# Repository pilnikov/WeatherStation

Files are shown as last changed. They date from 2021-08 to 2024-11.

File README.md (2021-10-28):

# WeatherStations

Проект метеостанции на ESP8266/32 (среда - Arduino IDE 1.8.5)

Поддерживаются:

Дисплеи на 7ми и 14ти сегментных индикаторах с драйверами на TM1637, HT16K33, MAX7219 (4/8 Знакомест).

LCD16х2 дисплей со встроеным знакогенератором кириллицы, интерфейс  I2C.

Матричные дисплеи на:
        
        MAX7219 8х32 и 16х32 пикселей.
        отдельном контроллере MEGA2560, 16х32 пикселей, полный цвет, интерфейс HUB75
        в версии ЕСП32, 64х64 пикселей, полный цвет, интерфейс HUB75 
        Holtek HT1632, 16х32 пикселей, 3 цвета (R, G, Orange) от Sure Electronics

Модули RTC на DS1307, DS1302, DS3231.

Управление яркостью дисплеев посредством датчика освещенности ВН1750 или фоторезистора.

Погодные датчики DHT22, Si7021, BME(/P)085/180/280, AM2320, вcтроеный в DS3231 датчик температуры.

Обмен данными между 2мя и более устройствами внутри сети посредством JSON запросов и через облачный сервис ThingSpeak.

Клиент/серверная архитектура.

Возможность работы в режиме "WiFi датчик".

Прогноз погоды с GisMeteo и OpenWeatherMap.

Синхронизация времени с NTP.

6 многофункциональных будильников с 15ю мелодиями.

Настойка через веб интерфейс.

Обновление по OTA, mdns.

Новости с newsapi.

Конфигурирование GPIO.

Дауншифтовая версия на MEGA2560 без возможности перенастройки, без прогноза, без новостей.

Немного мультиков
https://yadi.sk/i/UXBMaSDD3HfCZC

https://yadi.sk/i/Ew0egvWq3Hg48u

https://yadi.sk/i/os1wRLuz3Hg493

https://yadi.sk/i/jCs5TbVB3aA5pw теперь только один мк, безо всяких мег

https://youtu.be/F3vVPQLzyJk версия с новостями, там же есть ссылки на фото платы

Cхемы в папочке extras, там же и инфа для изготовления печатных плат.

Файлы из папки Data необходимо залить на LittleFS плагином (лежат в  папке dop).

По умолчанию первый раз запускается точка доступа с именем  Web_Clock и паролем 12345678 (задается в файле config.json из папки data перед загрузкой в LittleFS строкой  "ap_ssid":"Web_Clock","ap_pass":"12345678").Веб интерфейс будет доступен по адресу 192.168.4.1.

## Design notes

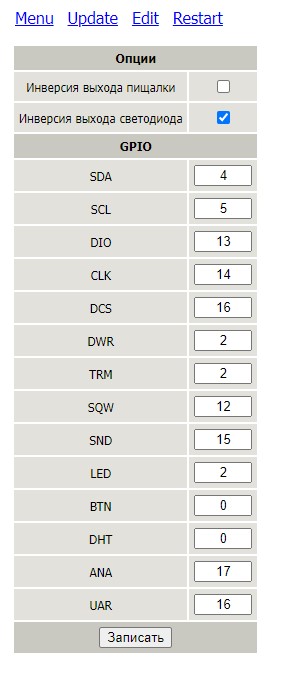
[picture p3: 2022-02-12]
wc_rt1/images/gpio.JPG

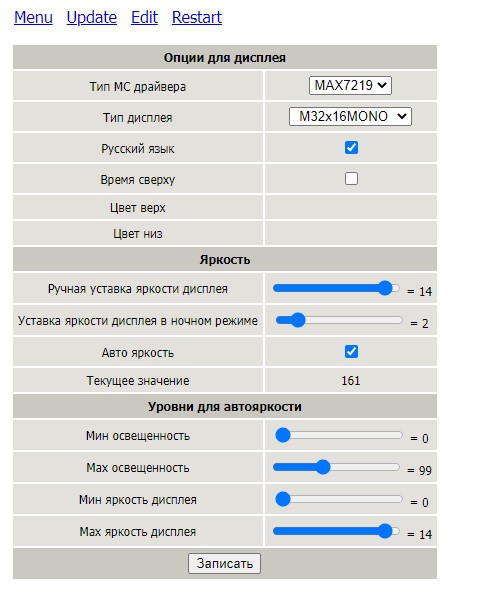
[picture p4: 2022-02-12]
wc_rt1/images/disp.JPG

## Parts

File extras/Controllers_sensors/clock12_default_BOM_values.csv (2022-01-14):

Qty | Value | Device | Parts | Description | OC_FARNELL | OC_NEWARK | PROD_ID | VALUE
10 | 10u | CAP0603-CAP | C101, C102, C104, C105, C108, C111, C112, C205, C206, C210 | Capacitor
13 | 0.1u | CAP0603-CAP | C103, C106, C107, C109, C201, C203, C207, C208, C211, C212, C302, C303, C307 | Capacitor
9 | 1u | CAP0603-CAP | C110, C113, C114, C115, C202, C204, C209, C305, C306 | Capacitor
2 | 22u | CAP0603-CAP | C301, C304 | Capacitor
1 | 1N5819 | DIODE-SOD123 | D201 | DIODE
1 | CRG | LED-YELLOW0603 | D202 | Yellow SMD LED |  |  | DIO-09003 | Yellow
2 | IN5819 | DIODE-SOD123 | D301, D302 | DIODE
1 | BATTERY-LI-MH12210 | BATTERY-LI-MH12210 | G201 | Lithium-Ion MH12210 Rechargeable Battery
1 | ESP32C3 | ESP32C3-MODULE32S | IC101
1 | ESP32 | ESP32-MODULEDUAL | IC102
1 | ESP32C3-MODULE13U | ESP32C3-MODULE13U | IC103
1 | ESP32S2 | ESP32S2-MODULEAI | IC104
5 | AP2112 | V_REG_LDOSMD | IC201, IC301, U101, U102, U103 | Voltage Regulator LDO |  |  | VREG-12457
1 | SI7021 | SI7021 | IC202 | Silicon Labs Si7021 I2C Humidity and Temperature Sensor |  |  | IC-13093
1 | MCP73831 | MCP73831 | IC203 | Miniature single cell, fully integrated Li-Ion, Li-polymer charge management controller |  |  | IC-09995
1 | BME280 | BME280 | IC204 | Bosch BME280 &ndash; Combined Humidity and Pressure Sensor |  |  | IC-13090 | BME280
1 | BH1750 | BH1750 | IC205 |  |  |  | IC-13876 | ZOPT2201
1 | CP2102 | CP2102-GMR(QFN28) | IC302 | 310070003 |  |  |  | CP2102-GMR-QFN28
3 |  | USB_MICRO-BFEMALE_SMT_ | J101, J106, J107 | USB Type Micro-B Connector
4 | COM | HEADER-2X3SMT | J102, J103, J104, J105 | PIN HEADER
2 |  | HEADER-2X8 | J108, J111 | PIN HEADER
2 |  | HEADER-2X13 | J109, J110 | PIN HEADER
2 |  | USB_C16PIN | J201, J302 | USB Type C 16Pin Connector |  |  | CONN-14122
1 | FR | CONN_03 | J202 | Multi connection point. Often used as Generic Header-pin footprint for 0.1 inch spaced/style header connections |  |  | XXX-00000 | 455-1750-1-ND
1 |  | HEADER-2X5 | J203 | PIN HEADER
1 | DHT22 | C-GRID-04-70543 | J204 | CONNECTOR | unknown | unknown
2 | +5V | C-GRID-02-70543 | J205, J303 | CONNECTOR | unknown | unknown
1 | AM2320 | C-GRID-04-70543 | J206 | CONNECTOR | unknown | unknown
1 | LiPo | CONN_02-JST-2MM-SMT | J207 | Multi connection point. Often used as Generic Header-pin footprint for 0.1 inch spaced/style header connections |  |  | CONN-11443
1 | PROG | JST-SH-1MM-8 | J301
1 | COM1 | HEADER-2X3SMT_1.27 | J304 | PIN HEADER
1 | COM2 | HEADER-2X3SMT | J305 | PIN HEADER
1 | 2301 | MOSFET-PCHANNELDMG2307L | Q201 | Generic PMOSFET |  |  | TRANS-11308 | 2.5A/30V
1 |  | SMD-MOSFET-DUAL-N-CH-30V-2.9A-SI5902DC-T1-E3(1206-8)SOT363 | Q301 | 305040005
6 | 100k | R-EU_R0603 | R101, R103, R104, R206, R207, R301 | RESISTOR, European symbol
10 | 10k | R-EU_R0603 | R102, R105, R106, R107, R204, R210, R212, R303, R304, R305 | RESISTOR, European symbol
2 | 47k | R-EU_R0603 | R201, R202 | RESISTOR, European symbol
2 | 5.1k | R-EU_R0603 | R203, R302 | RESISTOR, European symbol
1 | 27k | R-EU_R0603 | R205 | RESISTOR, European symbol
3 | 1k | R-EU_R0603 | R208, R209, R215 | RESISTOR, European symbol
3 | 2k | R-EU_R0603 | R211, R307, R308 | RESISTOR, European symbol
2 | 3k3 | R-EU_R0603 | R213, R214 | RESISTOR, European symbol
1 | 4.7k | R-EU_R0603 | R306 | RESISTOR, European symbol
5 | RST | MICROSWITCH-BUTTON | SW101, SW103, SW104, SW105, SW301
5 | PRG | MICROSWITCH-BUTTON | SW102, SW106, SW107, SW108, SW302
1 | MICROSWITCH-BUTTONANGLE | MICROSWITCH-BUTTONANGLE | SW201
1 | BAT ON | SMD-TOGGLE-SWITCH-ON-ON(3+4P-6.7X2.7MM)ORIG | SW202 | 311030001

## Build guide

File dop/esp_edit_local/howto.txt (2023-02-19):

Для работы требуется написать в браузере "путь/index.htm?url=server". 
Вместо server к примеру пишем 192.168.211.180. 
Например у меня это выглядит так "C:/esp_edit_local/index.htm?url=192.168.211.180". 

Но есть одна ложка дегтя, не все браузеры поддерживают обработку параметров. 
11 Internet Explorer выдает ошибку, но в Edge все работает. 
У кого будет ошибка "файл не найден", вам надо править в файле index.htm переменную urlXXX. 
Очень важно косую не ставить в конце.

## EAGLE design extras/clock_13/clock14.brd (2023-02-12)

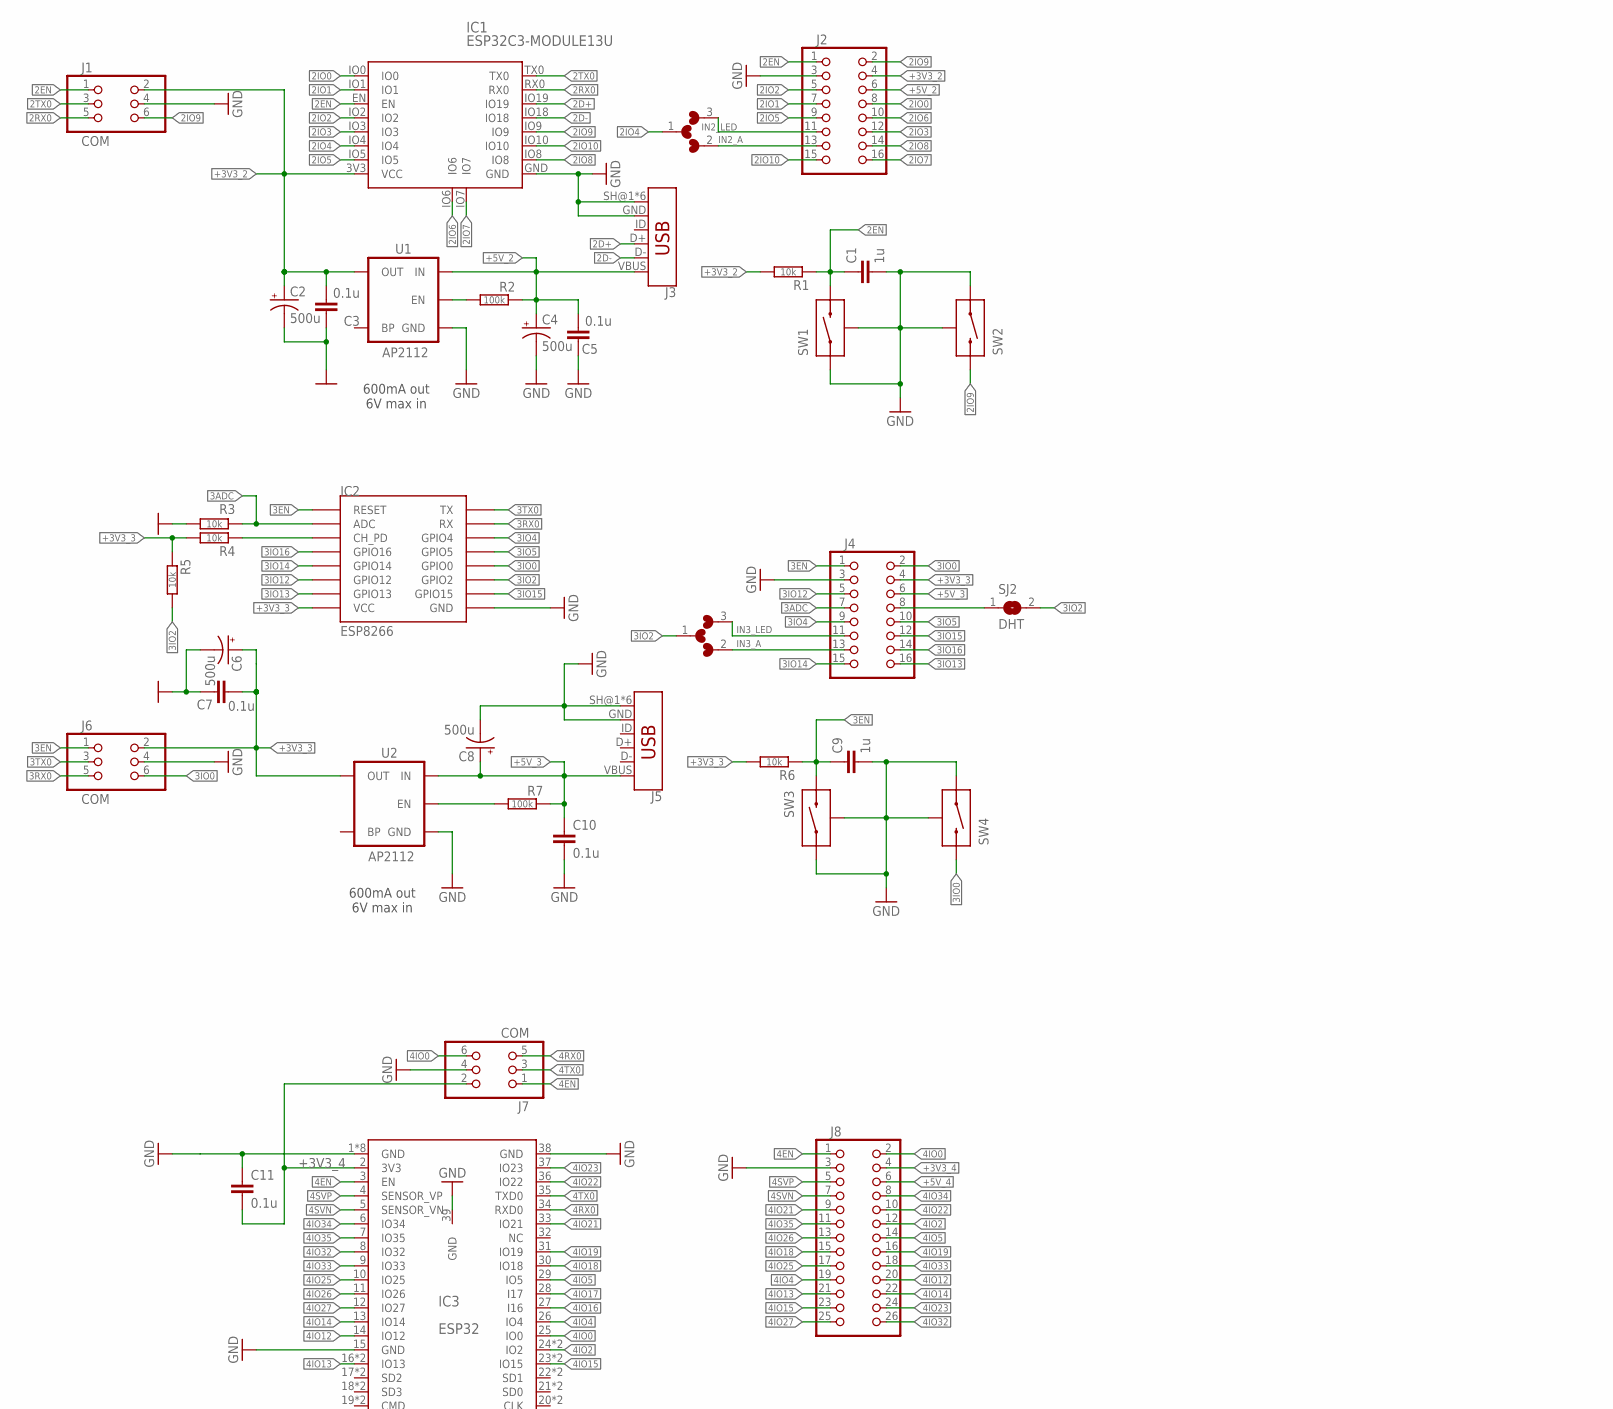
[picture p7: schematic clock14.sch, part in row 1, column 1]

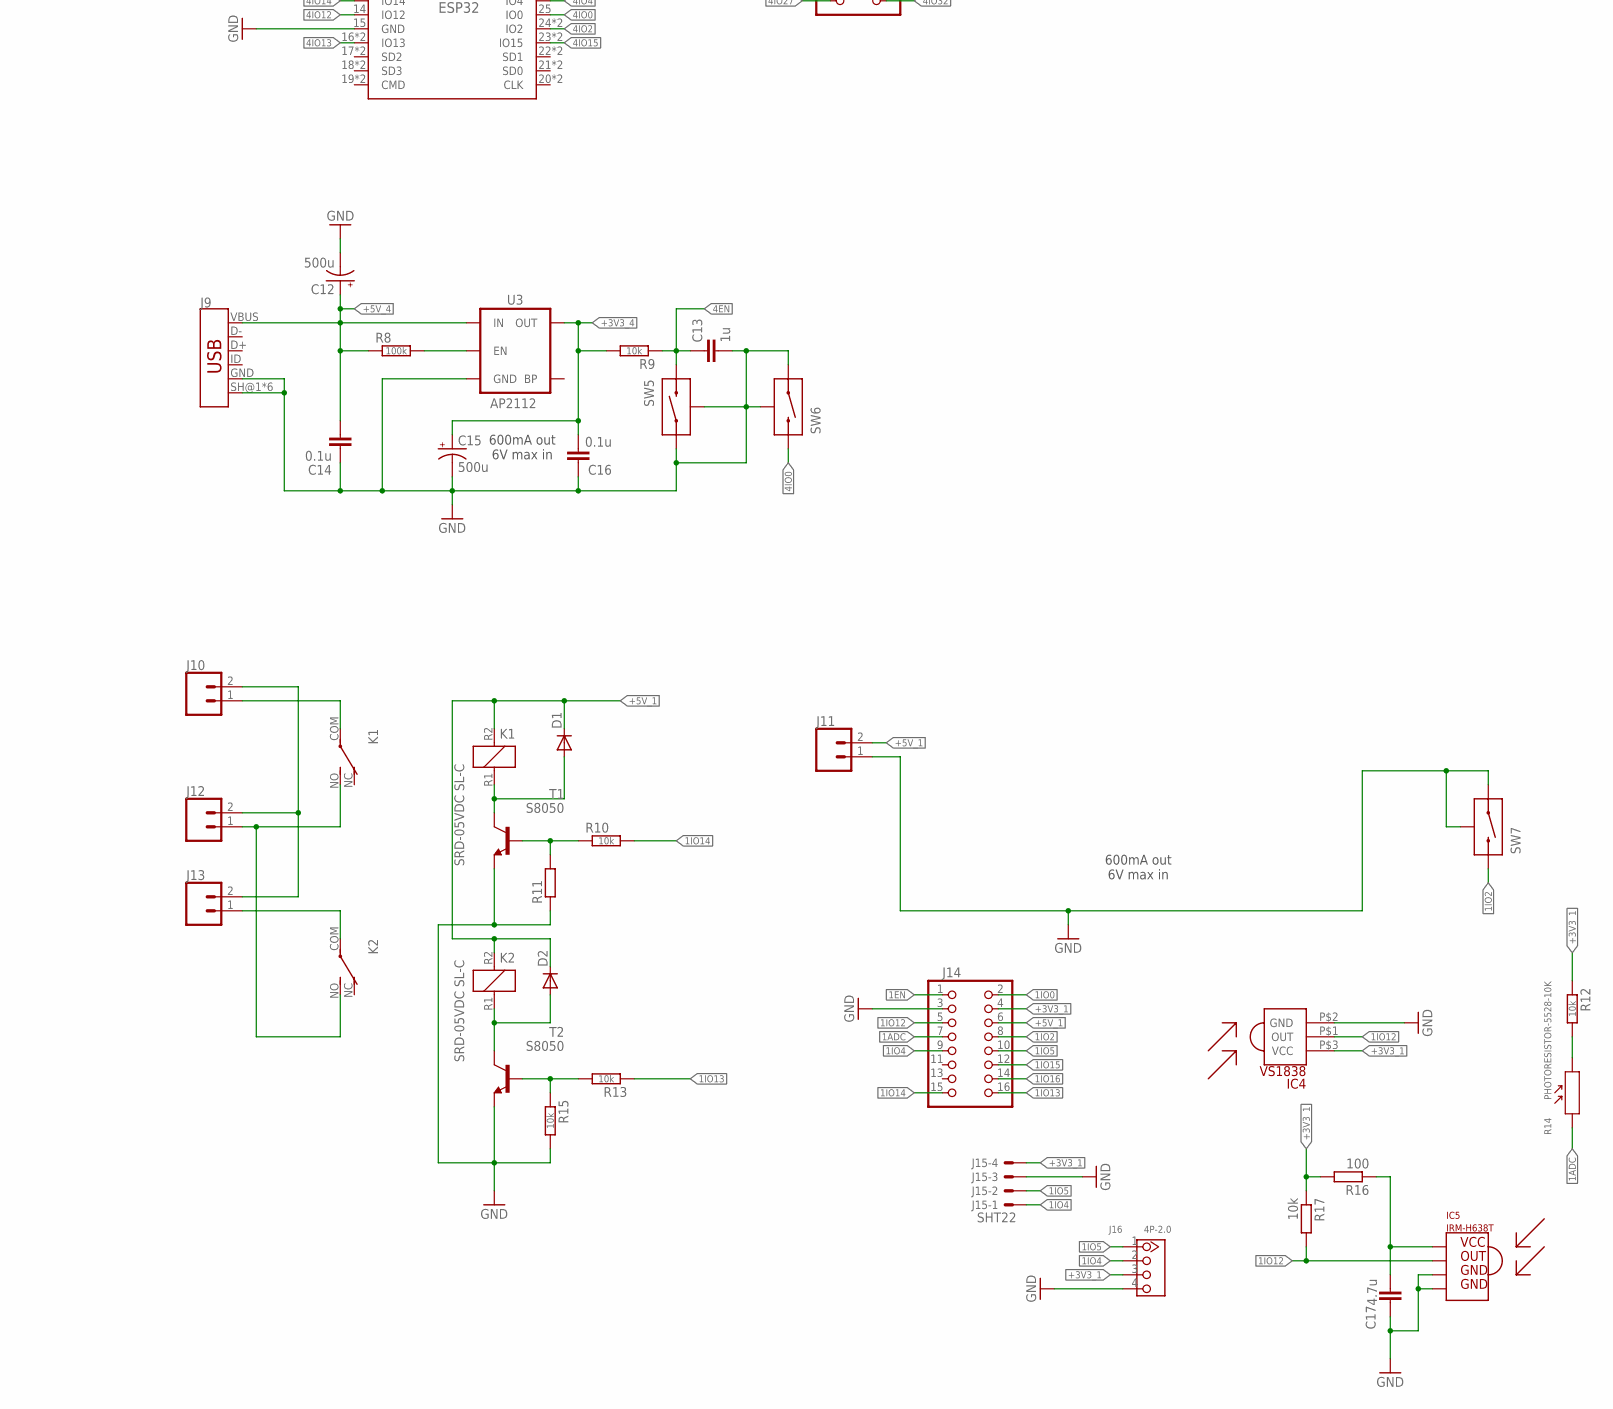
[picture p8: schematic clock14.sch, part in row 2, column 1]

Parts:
C1, C9, C13: 1u; 0603-CAP
C2, C4, C6, C8, C12, C15: 500u; CPOL-RADIAL-100UF-25V
C3, C5, C7, C10, C11, C14, C16: 0.1u; 0603-CAP
C17: 4.7u; 0603-CAP
D1, D2: DIODE-SOD123; SOD123
IC1: ESP32C3-MODULE13U; ESP32C3-13U
IC2: ESP8266; ESP12-SMD
IC3: ESP32; ESP32-WROOVER/WROOM
IC4: VS1838; IR
IC5: IRM-H638T
J1, J6, J7: COM; 2X03_SMT
J2, J4, J14: HEADER-2X8; 2X8
J3, J5, J9: USB_MICRO-BFEMALE_SMT_; USB-B-MICRO-SMD_MY
J8: HEADER-2X13; 2X13
J10, J11, J12, J13: CONN_02; 1X02
J15: SHT22; 70543-04
J16: 4P-2.0; HW4-2.0
K1, K2: SRD-05VDC SL-C; SL-C
R1, R3, R4, R5, R6, R9, R10, R12, R13, R15, R17: 10k; R0603
R2, R7, R8: 100k; R0603
R11: R-EU_R0603; R0603
R14: PHOTORESISTOR-5528-10K; SNR2-3.0
R16: 100; R0603
SJ1, SJ3: L/W; MICROBUILDER_SOLDERJUMPER_ARROW_NOPASTE_3
SJ2: DHT; MICROBUILDER_SOLDERJUMPER_ARROW_NOPASTE
SW1, SW3, SW5: RST; MICROPUSH-BUT_TOP
SW2, SW4, SW6, SW7: PRG; MICROPUSH-BUT_TOP
T1, T2: S8050; SOT23-EBC
U1, U2, U3: AP2112; SOT23-5

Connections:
1ADC: J14.7, R14.1
1EN: J14.1
1EN_P: R8.2, U3.3 (EN)
1IO0: J14.2
1IO2: J14.8, SW7.B
1IO4: J14.9, J15.1, J16.2
1IO5: J14.10, J15.2, J16.1
1IO12: IC4.P$1 (OUT), IC5.OUT, J14.5, R17.2
1IO13: J14.16, R13.1
1IO14: J14.15, R10.2
1IO15: J14.12
1IO16: J14.14
2D+: IC1.IO19, J3.D+
2D-: IC1.IO18, J3.D-
2EN: C1.1, IC1.EN, J1.1, J2.1, R1.1, SW1.B
2EN_P: R2.2, U1.3 (EN)
2IO0: IC1.IO0, J2.8
2IO1: IC1.IO1, J2.7
2IO2: IC1.IO2, J2.5
2IO3: IC1.IO3, J2.12
2IO4: IC1.IO4, SJ1.1
2IO5: IC1.IO5, J2.9
2IO6: IC1.IO6, J2.10
2IO7: IC1.IO7, J2.16
2IO8: IC1.IO8, J2.14
2IO9: IC1.IO9, J1.6, J2.2, SW2.B
2IO10: IC1.IO10, J2.15
2RX0: IC1.RX0, J1.5
2TX0: IC1.TX0, J1.3
3ADC: IC2.ADC, J4.7, R3.1
3EN: C9.1, IC2.RESET, J4.1, J6.1, R6.1, SW3.B
3EN_P: R7.2, U2.3 (EN)
3IO0: IC2.GPIO0, J4.2, J6.6, SW4.B
3IO2: IC2.GPIO2, R5.2, SJ2.2, SJ3.1
3IO4: IC2.GPIO4, J4.9
3IO5: IC2.GPIO5, J4.10
3IO12: IC2.GPIO12, J4.5
3IO13: IC2.GPIO13, J4.16
3IO14: IC2.GPIO14, J4.15
3IO15: IC2.GPIO15, J4.12
3IO16: IC2.GPIO16, J4.14
3RX0: IC2.RXD0 (RX), J6.5
3TX0: IC2.TXD0 (TX), J6.3
4EN: C13.1, IC3.3 (EN), J7.1, J8.1, R9.1, SW5.B
4IO0: IC3.25 (IO0), J7.6, J8.2, SW6.B
4IO2: IC3.24 (IO2), IC3.48 (IO2), J8.12
4IO4: IC3.26 (IO4), J8.19
4IO5: IC3.29 (IO5), J8.14
4IO12: IC3.14 (IO12), J8.20
4IO13: IC3.16 (IO13), IC3.40 (IO13), J8.21
4IO14: IC3.13 (IO14), J8.22
4IO15: IC3.23 (IO15), IC3.47 (IO15), J8.23
4IO16: IC3.27 (I16)
4IO17: IC3.28 (I17)
4IO18: IC3.30 (IO18), J8.15
4IO19: IC3.31 (IO19), J8.16
4IO21: IC3.33 (IO21), J8.9
4IO22: IC3.36 (IO22), J8.10
4IO23: IC3.37 (IO23), J8.24
4IO25: IC3.10 (IO25), J8.17
4IO26: IC3.11 (IO26), J8.13
4IO27: IC3.12 (IO27), J8.25
4IO32: IC3.8 (IO32), J8.26
4IO33: IC3.9 (IO33), J8.18
4IO34: IC3.6 (IO34), J8.8
4IO35: IC3.7 (IO35), J8.11
4RX0: IC3.34 (RXD0), J7.5
4SVN: IC3.5 (SENSOR_VN), J8.7
4SVP: IC3.4 (SENSOR_VP), J8.5
4TX0: IC3.35 (TXD0), J7.3
+3V3_1: IC4.P$3 (VCC), J14.4, J15.4, J16.3, R12.1, R16.2, R17.1
+3V3_2: C2.1 (+), C3.2, IC1.3V3 (VCC), J1.2, J2.4, R1.2, U1.5 (OUT)
+3V3_3: C6.1 (+), C7.2, IC2.VCC, J4.4, J6.2, R4.2, R5.1, R6.2, U2.5 (OUT)
+3V3_4: C11.2, C15.1 (+), C16.2, IC3.2 (3V3), J7.2, J8.4, R9.2, U3.5 (OUT)
+5V_1: D1.C, D2.C, J11.2, J14.6, K1.R2 (2), K2.R2 (2)
+5V_2: C4.1 (+), C5.2, J2.6, J3.VBUS, R2.1, U1.1 (IN)
+5V_3: C8.1 (+), C10.1, J4.6, J5.VBUS, R7.1, U2.1 (IN)
+5V_4: C12.1 (+), C14.1, J8.6, J9.VBUS, R8.1, U3.1 (IN)
GND: C1.2, C2.2 (-), C3.1, C4.2 (-), C5.1, C6.2 (-), C7.1, C8.2 (-), C9.2, C10.2, C11.1, C12.2 (-), C13.2, C14.2, C15.2 (-), C16.1, C17.2, IC1.GND, IC2.GND, IC3.1 (GND), IC3.15 (GND), IC3.38 (GND), IC3.39 (GND), IC3.GND, IC3.PAD$1 (GND), IC3.PAD$4 (GND), IC3.PAD$5 (GND), IC3.PAD$7 (GND), IC3.PAD$8 (GND), IC3.PAD$9 (GND), IC4.P$2 (GND), IC5.GND, IC5.GND1, J1.4, J2.3, J3.GND, J3.SH@1 (SHIELD), J3.SH@2 (SHIELD), J3.SH@3 (SHIELD), J3.SH@4 (SHIELD), J3.SH@5 (SHIELD), J3.SH@6 (SHIELD), J4.3, J5.GND, J5.SH@1 (SHIELD), J5.SH@2 (SHIELD), J5.SH@3 (SHIELD), J5.SH@4 (SHIELD), J5.SH@5 (SHIELD), J5.SH@6 (SHIELD), J6.4, J7.4, J8.3, J9.GND, J9.SH@1 (SHIELD), J9.SH@2 (SHIELD), J9.SH@3 (SHIELD), J9.SH@4 (SHIELD), J9.SH@5 (SHIELD), J9.SH@6 (SHIELD), J11.1, J14.3, J15.3, J16.4, R3.2, R11.1, R15.2, SW1.A, SW1.SH0 (SH), SW2.A, SW2.SH0 (SH), SW3.A, SW3.SH0 (SH), SW4.A, SW4.SH0 (SH), SW5.A, SW5.SH0 (SH), SW6.A, SW6.SH0 (SH), SW7.A, SW7.SH0 (SH), T1.E, T2.E, U1.2 (GND), U2.2 (GND), U3.2 (GND)
IN2_A: J2.13, SJ1.2
IN2_LED: J2.11, SJ1.3
IN3_A: J4.13, SJ3.2
IN3_DHT: J4.8, SJ2.1
IN3_LED: J4.11, SJ3.3
IN_L: J12.1, K1.NO, K2.NO
N: J10.2, J12.2, J13.2
unnamed: IC2.CH_PD, R4.1
unnamed: D1.A, K1.R1 (1), T1.C
unnamed: R10.1, R11.2, T1.B
unnamed: D2.A, K2.R1 (1), T2.C
unnamed: R13.2, R15.1, T2.B
unnamed: R12.2, R14.2
unnamed: C17.1, IC5.VCC, R16.1
OUT_L1: J10.1, K1.COM
OUT_L2: J13.1, K2.COM

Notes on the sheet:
600mA out 6V max in

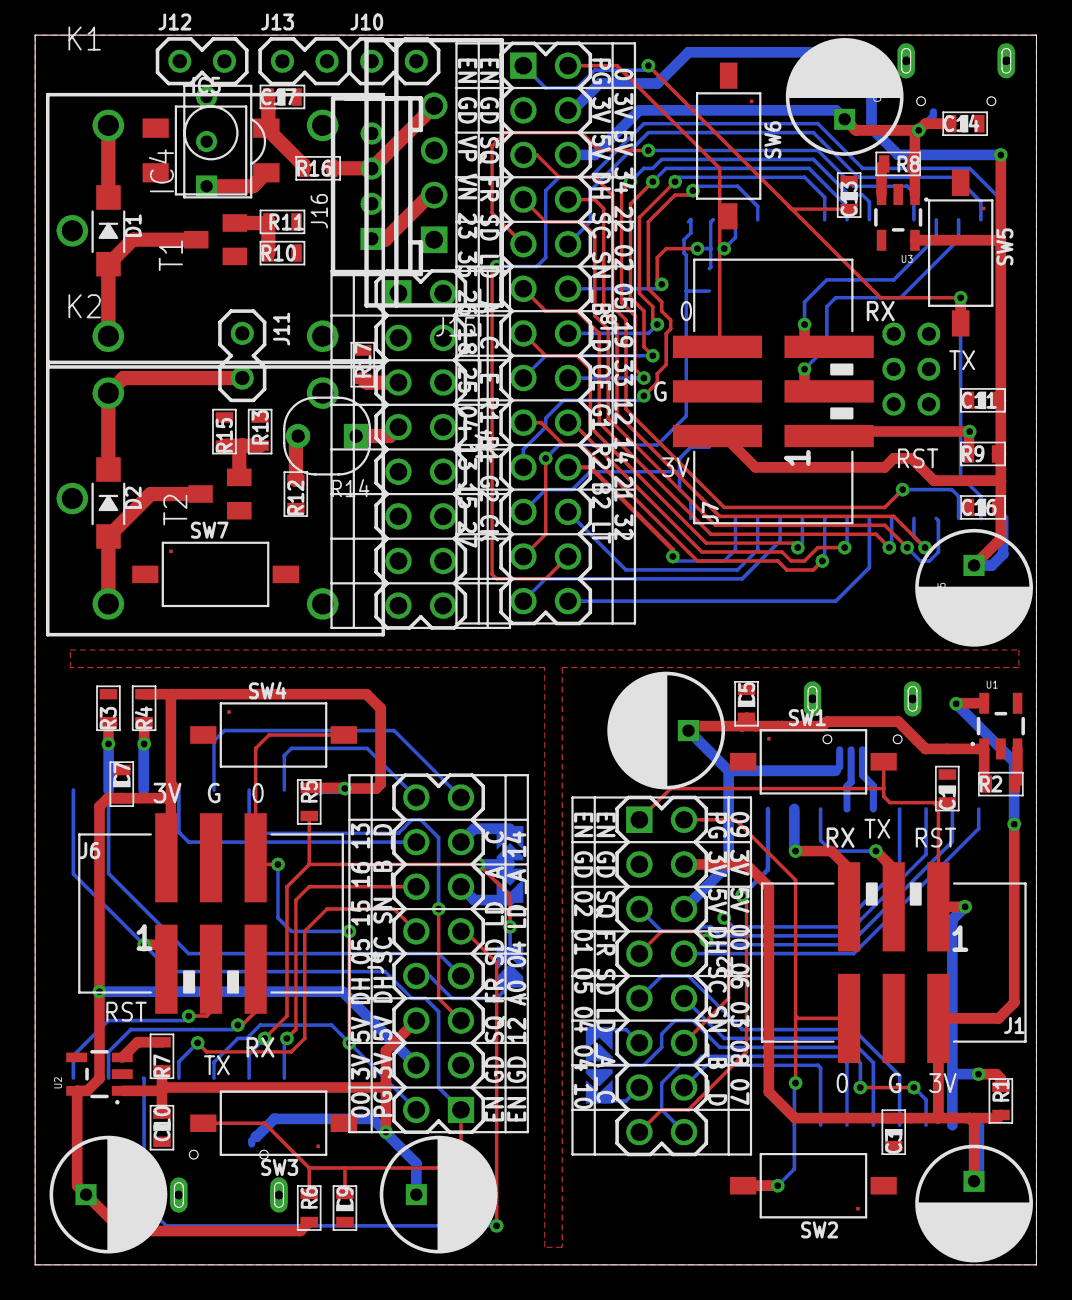
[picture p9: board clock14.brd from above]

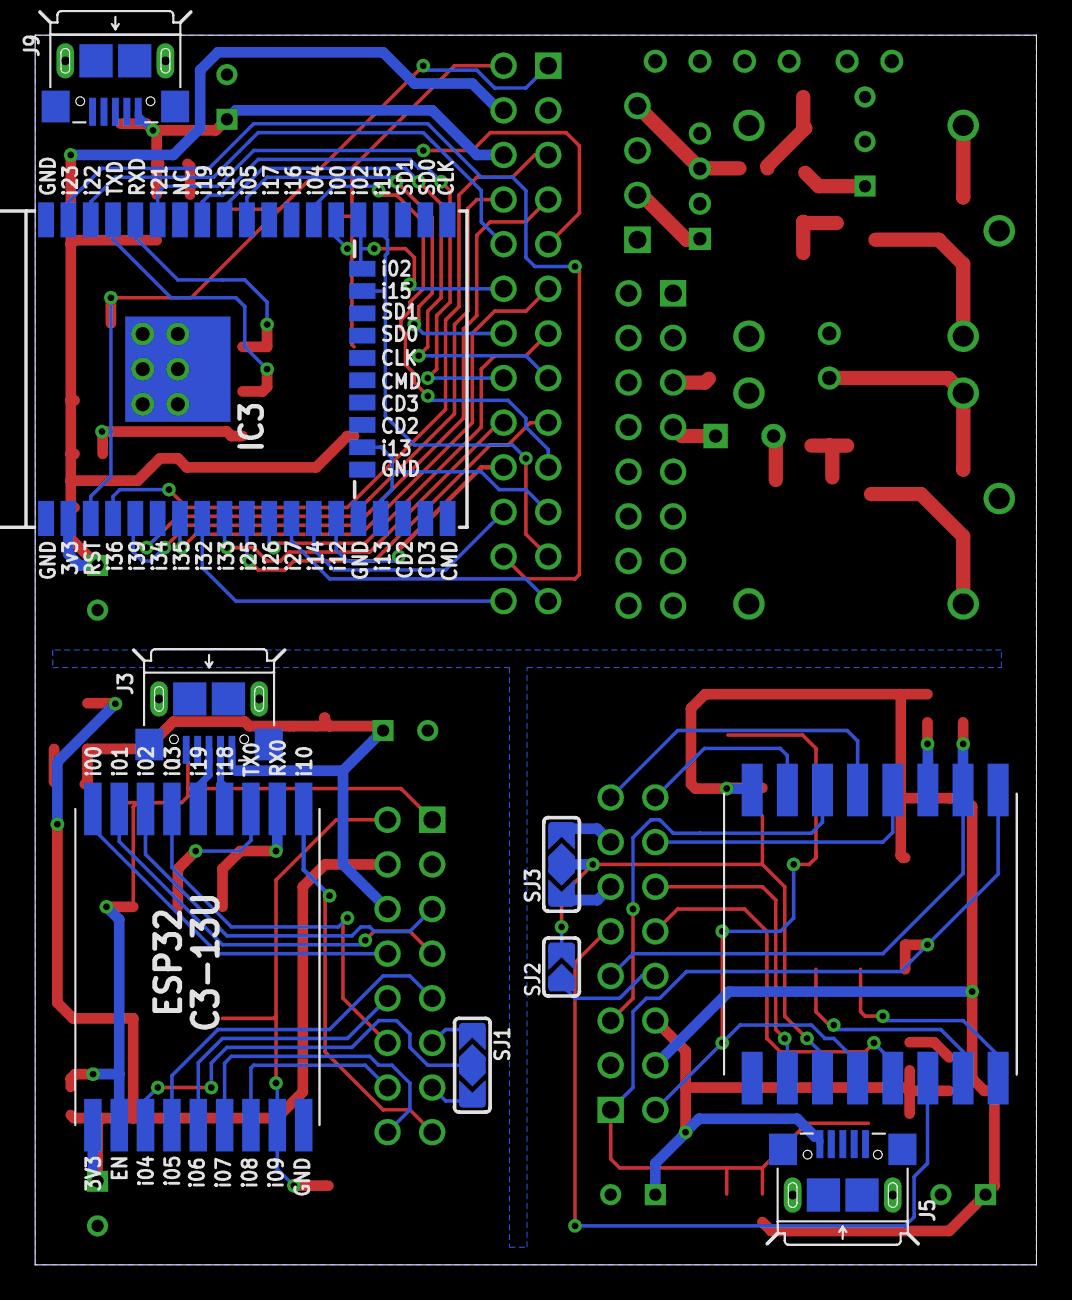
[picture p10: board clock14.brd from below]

Board: 2 copper layers, 57.0 x 70.0 mm, 74 parts (9 on the bottom side), 89 nets.

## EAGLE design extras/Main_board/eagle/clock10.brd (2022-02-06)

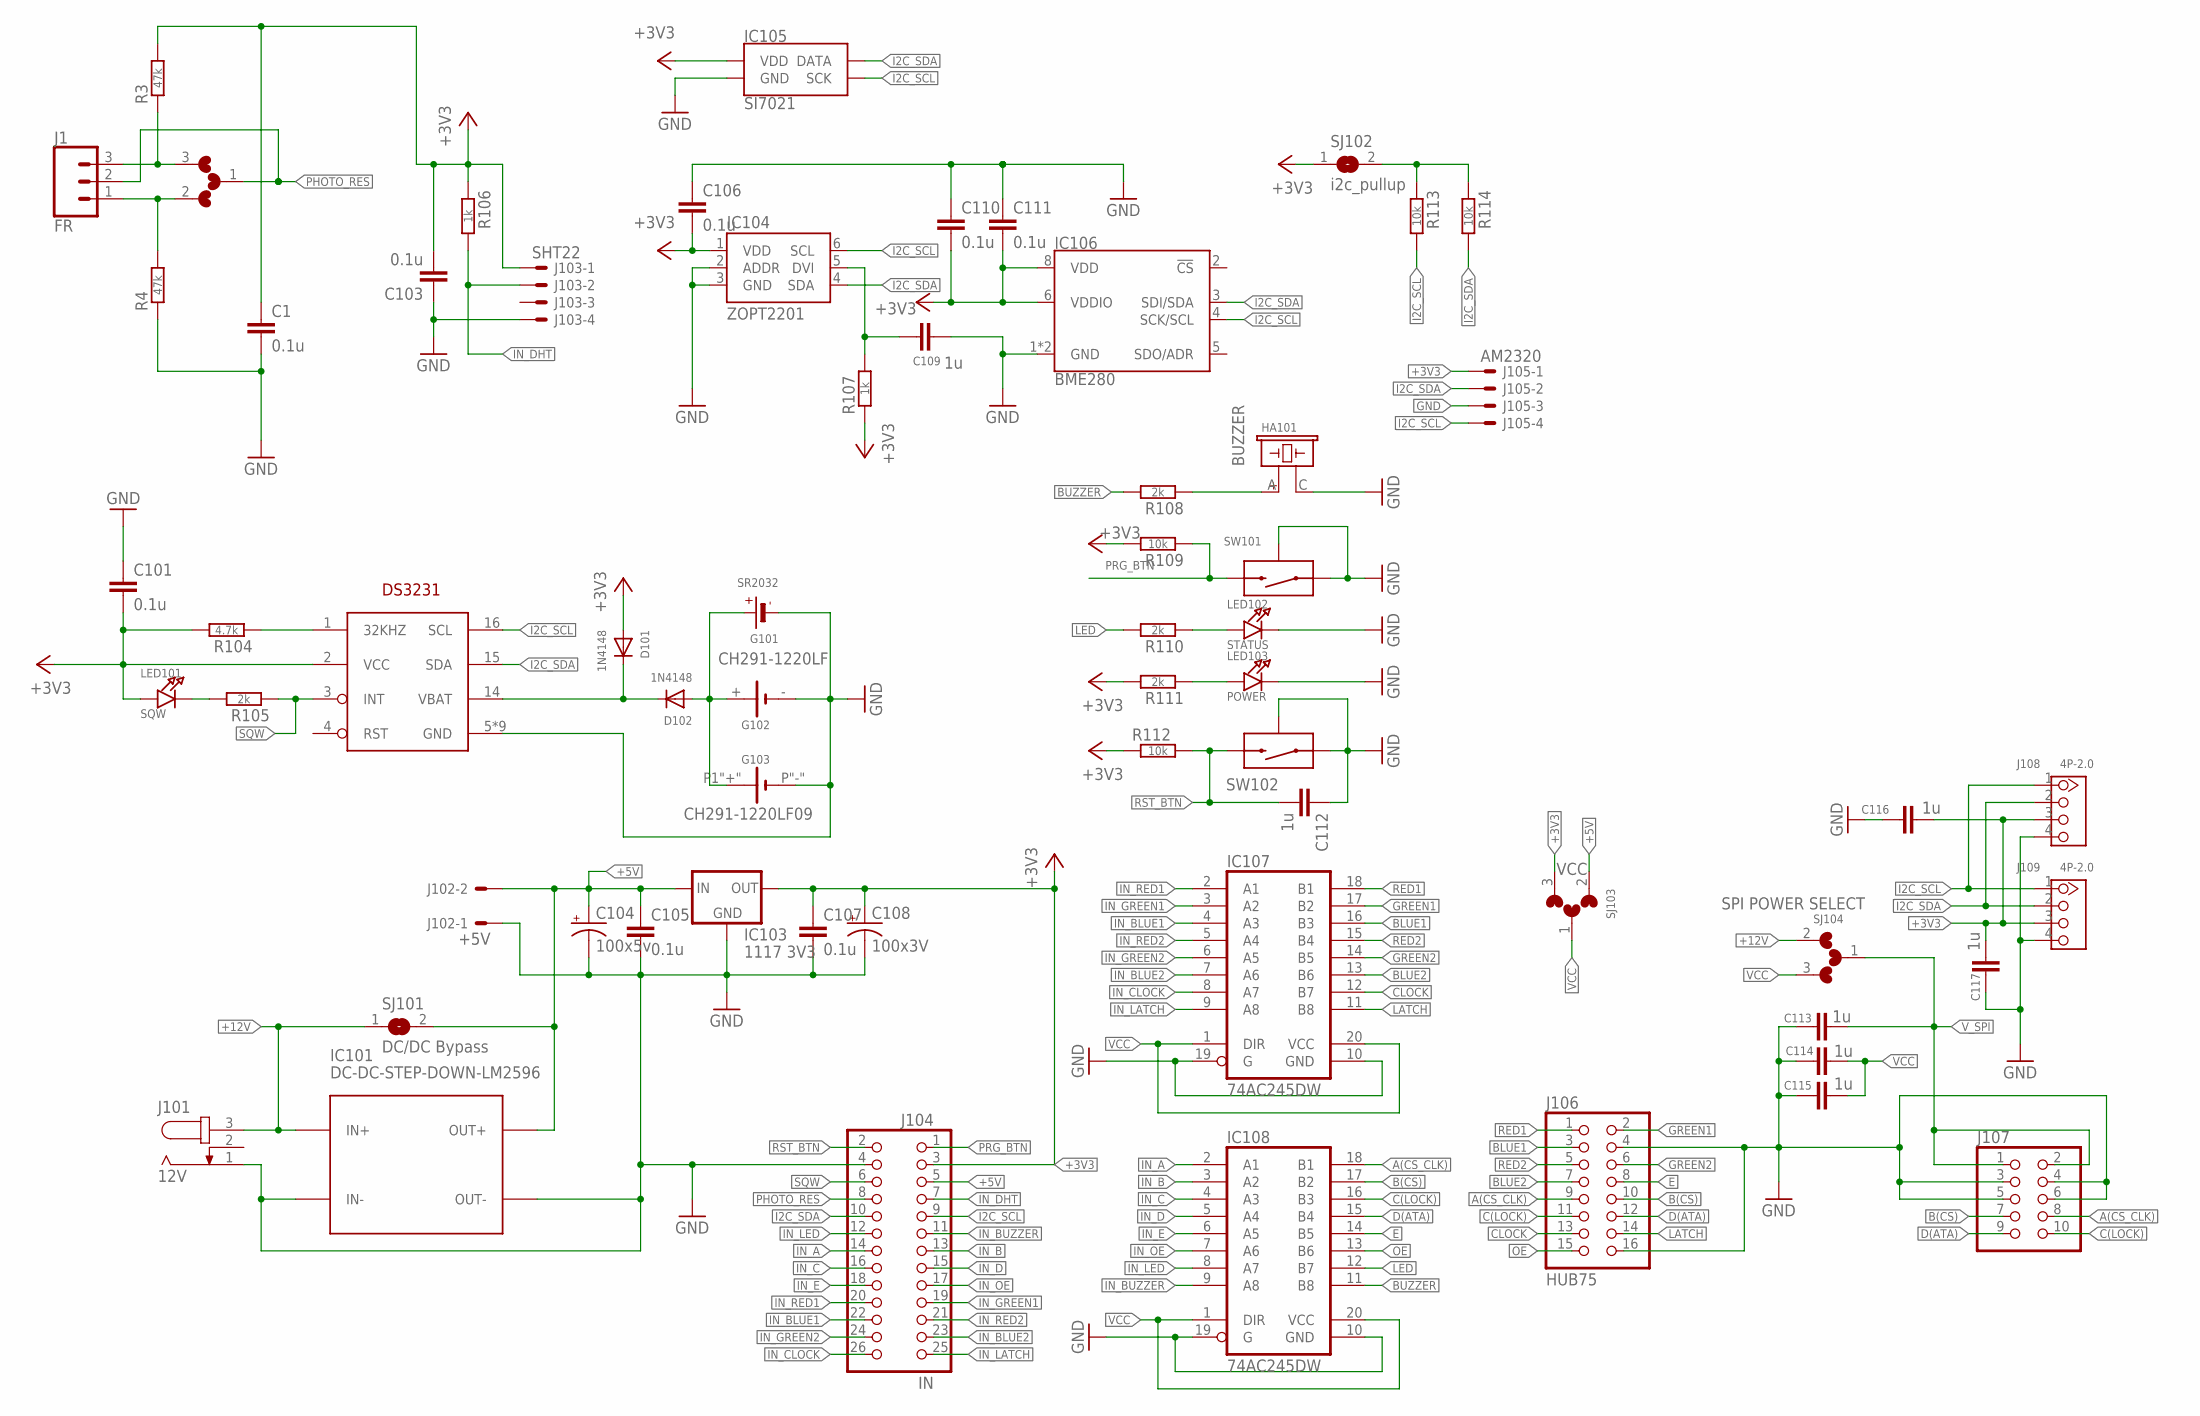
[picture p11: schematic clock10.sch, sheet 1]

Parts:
C1, C101, C103, C105, C106, C107, C110, C111: 0.1u; 0603-CAP
C104: 100x5v; CPOL-RADIAL-100UF-25V
C108: 100x3V; CPOL-RADIAL-100UF-25V
C109, C112, C113, C114, C115, C116, C117: 1u; 0603-CAP
D101, D102: 1N4148; SOD-323F
G101: SR2032; CR2032
G102: CH291-1220LF
G103: CH291-1220LF09; CH23-09LF
HA101: BUZZER; PBUZ_12X7.5
IC101: DC-DC-STEP-DOWN-LM2596
IC102: DS3231W; SO16W
IC103: 1117 3V3; SOT223
IC104: ZOPT2201; WSOF6L
IC105: SI7021; DFN-6-3X3-SI7021
IC106: BME280; LGA-8-2.5X2.5
IC107, IC108: 74AC245DW; SO20W
J1: FR; 1X03
J101: 12V; SPC4077
J102: +5V; 70543-02
J103: SHT22; 70543-04
J104: IN; 2X13
J105: AM2320; 70543-04
J106: HUB75; 2X08
J107: HEADER-2X5IDC; 2X05_IDC
J108, J109: 4P-2.0; HW4-2.0
LED101: SQW; CHIPLED_0603
LED102: STATUS; CHIPLED_0603
LED103: POWER; CHIPLED_0603
R3, R4: 47k; R0603
R104: 4.7k; R0603
R105, R108, R110, R111: 2k; R0603
R106, R107: 1k; R0603
R109, R112, R113, R114: 10k; R0603
SJ1: PR POS/NEG; MICROBUILDER_SOLDERJUMPER_ARROW_NOPASTE_3
SJ101: DC/DC Bypass; MICROBUILDER_SOLDERJUMPER_ARROW_NOPASTE
SJ102: i2c_pullup; MICROBUILDER_SOLDERJUMPER_ARROW_NOPASTE
SJ103: VCC; MICROBUILDER_SOLDERJUMPER_ARROW_NOPASTE_3
SJ104: SPI POWER SELECT; MICROBUILDER_SOLDERJUMPER_ARROW_NOPASTE_3
SW101: PRG; MICROPUSH-BUT_TOP
SW102: RST; MICROPUSH-BUT_TOP

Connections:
+3V3: C1.1, C101.2, C103.2, C106.2, C107.1, C108.1 (+), C110.2, C111.2, C116.2, C117.2, D101.A, IC102.2 (VCC), IC103.2 (OUT), IC103.4 (OUT), IC104.1 (VDD), IC105.VDD, IC106.6 (VDDIO), IC106.8 (VDD), J103.1, J104.3, J105.1, J108.3, J109.3, LED101.A, R3.2, R104.2, R106.1, R107.1, R109.2, R111.2, R112.1, SJ102.1, SJ103.3
+5V: C104.1 (+), C105.1, IC101.OUT+, IC103.3 (IN), J102.2, J104.5, SJ101.2, SJ103.2
+12V: IC101.IN+, J101.3, SJ101.1, SJ104.2
A(CS_CLK): IC108.18 (B1), J106.9, J107.8
B(CS): IC108.17 (B2), J106.10, J107.7
BLUE1: IC107.16 (B3), J106.3
BLUE2: IC107.13 (B6), J106.7
BUZ: HA101.A, R108.1
BUZZER: IC108.11 (B8), R108.2
C(LOCK): IC108.16 (B3), J106.11, J107.10
CLOCK: IC107.12 (B7), J106.13
D(ATA): IC108.15 (B4), J106.12, J107.9
E: IC108.14 (B5), J106.8
GND: C1.2, C101.1, C103.1, C104.2 (-), C105.2, C106.1, C107.2, C108.2 (-), C109.2, C110.1, C111.1, C112.1, C113.2, C114.2, C115.2, C116.1, C117.1, G101.-, G102.-, G103.P"-" (-), HA101.C, IC101.IN-, IC101.OUT-, IC102.5 (GND), IC102.6 (GND), IC102.7 (GND), IC102.8 (GND), IC102.9 (GND), IC102.10 (GND), IC102.11 (GND), IC102.12 (GND), IC102.13 (GND), IC103.1 (GND), IC104.2 (ADDR), IC104.3 (GND), IC105.GND, IC106.1 (GND), IC106.7 (GND), IC107.10 (GND), IC107.19 (G), IC108.10 (GND), IC108.19 (G), J101.1, J102.1, J103.4, J104.4, J105.3, J106.4, J106.16, J107.3, J107.4, J107.5, J107.6, J108.4, J109.4, LED102.C, LED103.C, R4.1, SW101.A, SW101.SH0 (SH), SW102.A, SW102.SH0 (SH); also elsewhere on the board
GREEN1: IC107.17 (B2), J106.2
GREEN2: IC107.14 (B5), J106.6
I2C_SCL: IC102.16 (SCL), IC104.6 (SCL), IC105.SCK, IC106.4 (SCK/SCL), J104.9, J105.4, J108.1, J109.1, R113.2
I2C_SDA: IC102.15 (SDA), IC104.4 (SDA), IC105.DATA, IC106.3 (SDI/SDA), J104.10, J105.2, J108.2, J109.2, R114.2
IN_A: IC108.2 (A1), J104.14
IN_B: IC108.3 (A2), J104.13
IN_BLUE1: IC107.4 (A3), J104.22
IN_BLUE2: IC107.7 (A6), J104.23
IN_BUZZER: IC108.9 (A8), J104.11
IN_C: IC108.4 (A3), J104.16
IN_CLOCK: IC107.8 (A7), J104.26
IN_D: IC108.5 (A4), J104.15
IN_DHT: J103.2, J104.7, R106.2
IN_E: IC108.6 (A5), J104.18
IN_GREEN1: IC107.3 (A2), J104.19
IN_GREEN2: IC107.6 (A5), J104.24
IN_LATCH: IC107.9 (A8), J104.25
IN_LED: IC108.8 (A7), J104.12
IN_OE: IC108.7 (A6), J104.17
IN_RED1: IC107.2 (A1), J104.20
IN_RED2: IC107.5 (A4), J104.21
LATCH: IC107.11 (B8), J106.14
LED: IC108.12 (B7), R110.2
unnamed: D101.C, D102.C, IC102.14 (VBAT)
unnamed: LED103.A, R111.1
unnamed: J1.3, R3.1, SJ1.3
unnamed: LED102.A, R110.1
unnamed: LED101.C, R105.2
unnamed: J1.1, R4.2, SJ1.2
unnamed: C109.1, IC104.5 (DVI), R107.2
unnamed: IC102.1 (32KHZ), R104.1
unnamed: R113.1, R114.1, SJ102.2
unnamed: D102.A, G101.+, G102.+, G103.P1"+" (+)
OE: IC108.13 (B6), J106.15
PHOTO_RES: J1.2, J104.8, SJ1.1
PRG_BTN: J104.1, R109.1, SW101.B
RED1: IC107.18 (B1), J106.1
RED2: IC107.15 (B4), J106.5
RST_BTN: C112.2, J104.2, R112.2, SW102.B
SQW: IC102.3 (INT), J104.6, R105.1
VCC: C114.1, C115.1, IC107.1 (DIR), IC107.20 (VCC), IC108.1 (DIR), IC108.20 (VCC), SJ103.1, SJ104.3
V_SPI: C113.1, J107.1, J107.2, SJ104.1

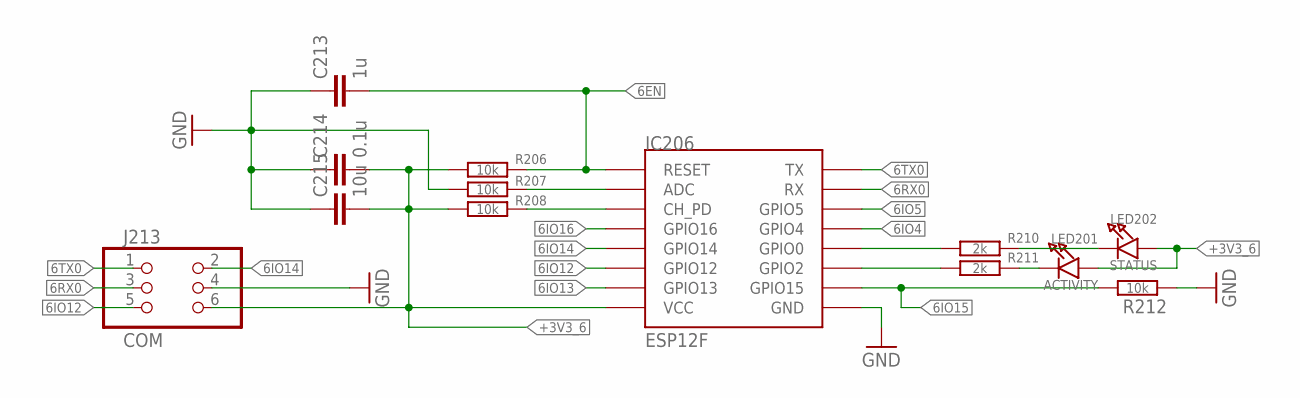
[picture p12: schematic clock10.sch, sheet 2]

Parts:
C213: 1u; 0603-CAP
C214: 0.1u; 0603-CAP
C215: 10u; 0603-CAP
IC206: ESP12F; ESP12-SMD
J213: COM; 2X03_SMT
LED201: ACTIVITY; CHIPLED_0603
LED202: STATUS; CHIPLED_0603
R206, R207, R208, R212: 10k; R0603
R210, R211: 2k; R0603

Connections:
6EN: C213.2, IC206.RESET, R206.1
6IO0: IC206.GPIO0, R210.1
6IO2: IC206.GPIO2, R211.1
6IO4: IC206.GPIO4
6IO5: IC206.GPIO5
6IO12: IC206.GPIO12, J213.5
6IO13: IC206.GPIO13
6IO14: IC206.GPIO14, J213.2
6IO15: IC206.GPIO15, R212.2
6IO16: IC206.GPIO16
6RX0: IC206.RXD0 (RX), J213.3
6TX0: IC206.TXD0 (TX), J213.1
+3V3_6: C214.2, C215.2, IC206.VCC, J213.6, LED201.A, LED202.A, R206.2, R208.2
GND: C213.1, C214.1, C215.1, IC206.GND, J213.4, R207.2, R212.1; also elsewhere on the board
unnamed: IC206.CH_PD, R208.1
unnamed: IC206.ADC, R207.1
unnamed: LED202.C, R210.2
unnamed: LED201.C, R211.2

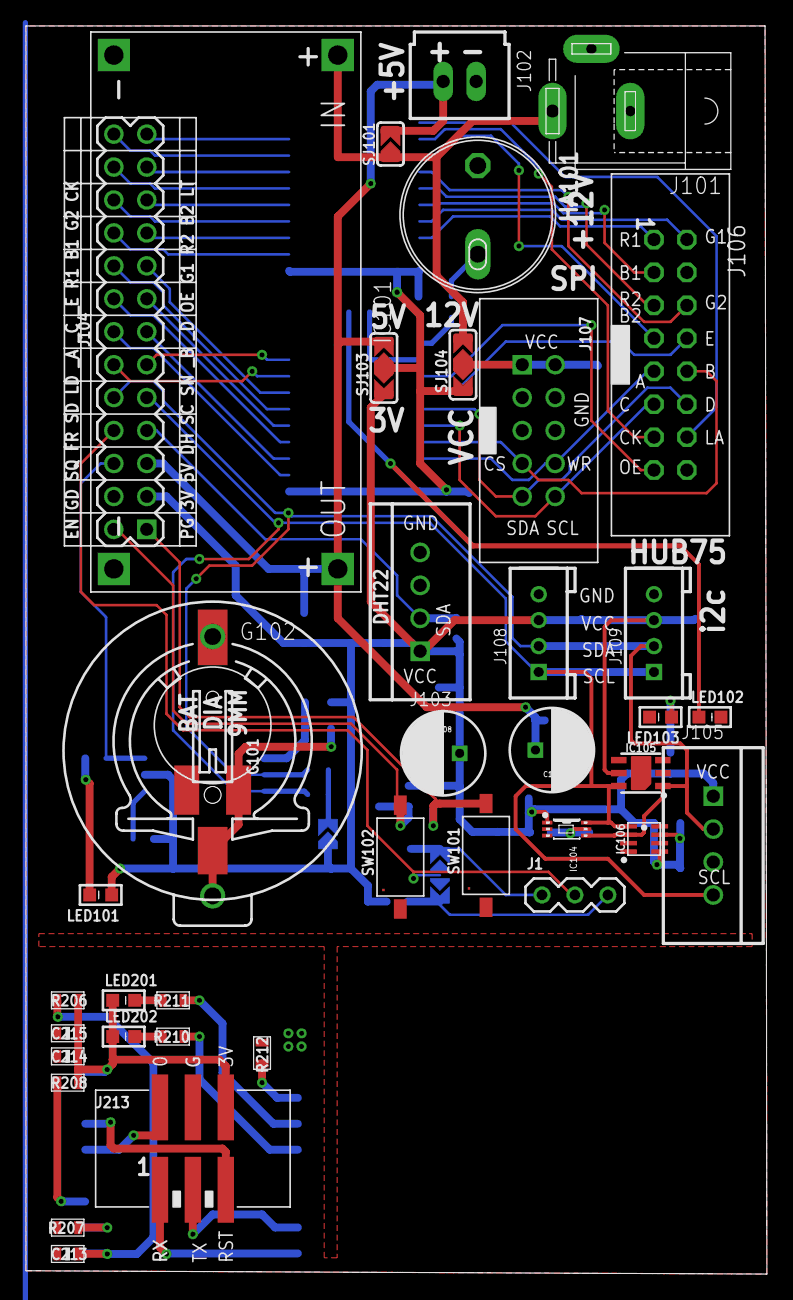
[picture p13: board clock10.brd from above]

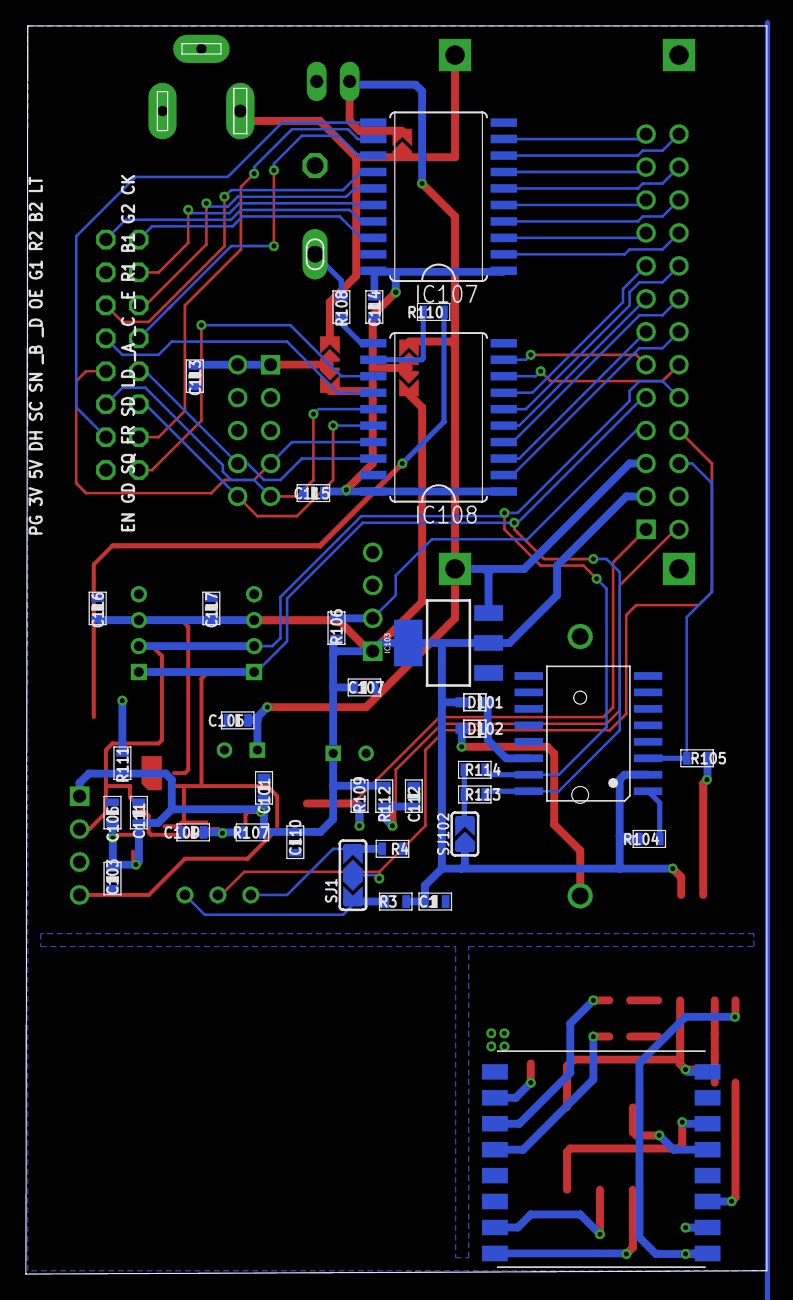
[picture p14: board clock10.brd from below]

Board: 2 copper layers, 57.1 x 96.3 mm, 77 parts (37 on the bottom side), 69 nets.

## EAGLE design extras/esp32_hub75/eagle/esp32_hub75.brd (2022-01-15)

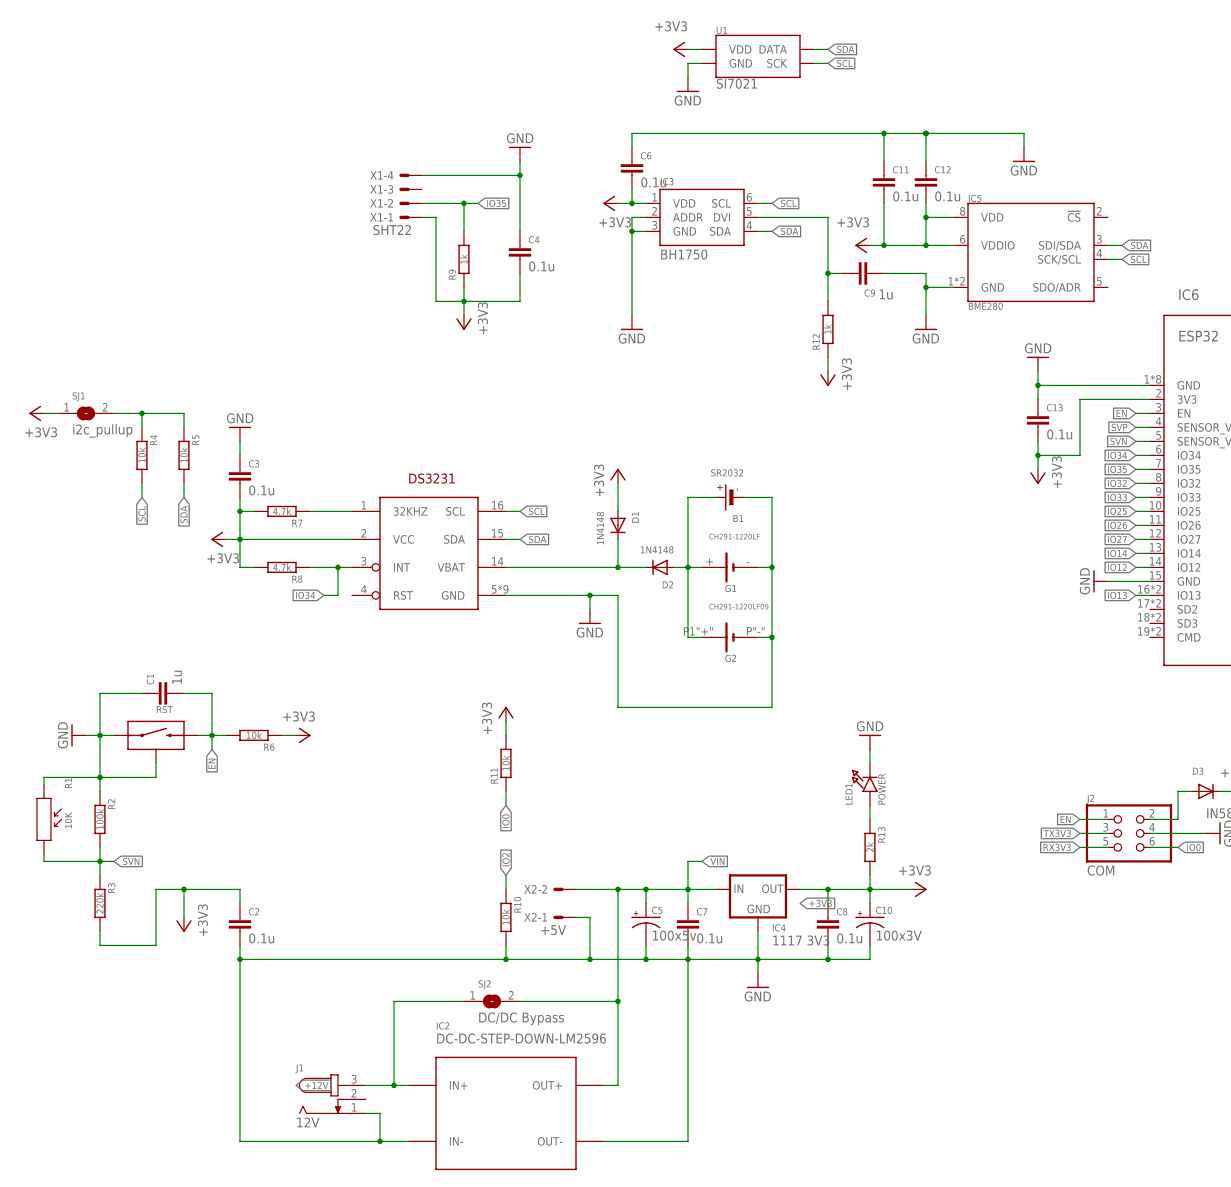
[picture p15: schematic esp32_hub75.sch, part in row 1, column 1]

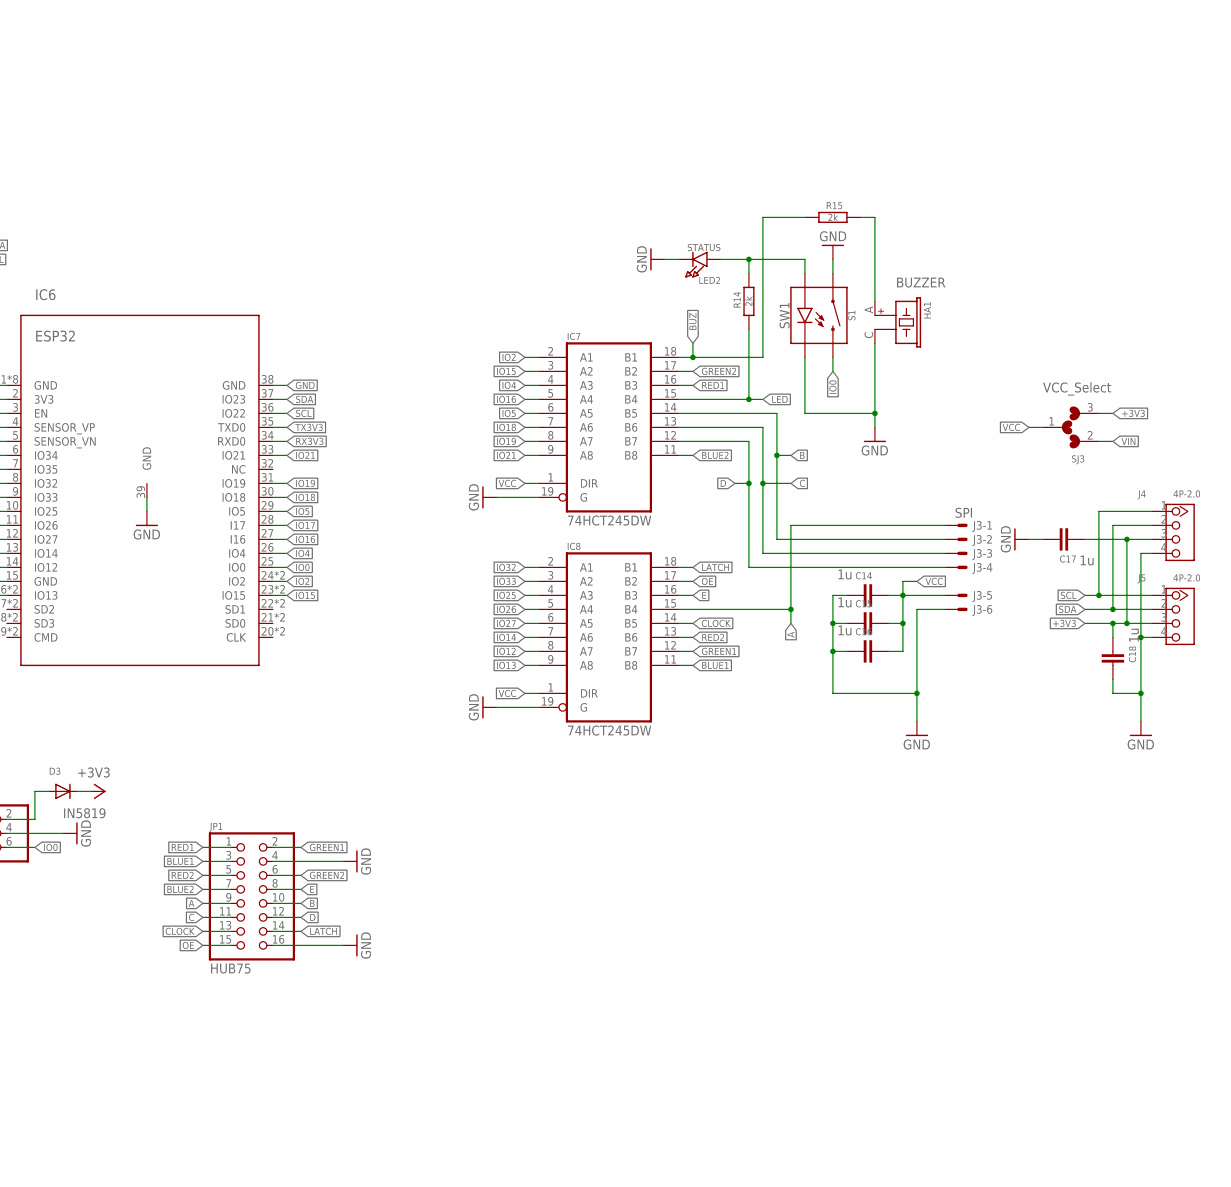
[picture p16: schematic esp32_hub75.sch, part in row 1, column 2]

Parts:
B1: SR2032; CR2032
C1, C9, C14, C15, C16, C17, C18: 1u; 0603-CAP
C2, C3, C4, C6, C7, C8, C11, C12, C13: 0.1u; 0603-CAP
C5: 100x5v; CPOL-RADIAL-100UF-25V
C10: 100x3V; CPOL-RADIAL-100UF-25V
D1, D2: 1N4148; SOD-323F
D3: IN5819; SOD123
G1: CH291-1220LF
G2: CH291-1220LF09; CH23-09LF
HA1: BUZZER; PBUZ_12X7.5
IC1: DS3231W; SO16W
IC2: DC-DC-STEP-DOWN-LM2596
IC3: BH1750; WSOF6L
IC4: 1117 3V3; SOT223
IC5: BME280; LGA-8-2.5X2.5
IC6: ESP32; ESP32-WROOVER/WROOM
IC7, IC8: 74HCT245DW; SO20W
J1: 12V; SPC4077
J2: COM; 2X03
J3: SPI; 70543-06
J4, J5: 4P-2.0; HW4-2.0
JP1: HUB75; 2X08
LED1: POWER; CHIPLED_0603
LED2: STATUS; CHIPLED_0603
R1: 10K; SNR2-3.0
R2: 100k; R0603
R3: 220k; R0603
R4, R5, R6, R10, R11: 10k; R0603
R7, R8: 4.7k; R0603
R9, R12: 1k; R0603
R13, R14, R15: 2k; R0603
RST: RST; MICROPUSH-BUT_TOP
S1: SW1; TACTILE_SWITCH_LED_PTH_12MM_KIT
SJ1: i2c_pullup; MICROBUILDER_SOLDERJUMPER_ARROW_NOPASTE
SJ2: DC/DC Bypass; MICROBUILDER_SOLDERJUMPER_ARROW_NOPASTE
SJ3: VCC_Select; MICROBUILDER_SOLDERJUMPER_ARROW_NOPASTE_3
U1: SI7021; DFN-6-3X3-SI7021
X1: SHT22; 70543-04
X2: +5V; 70543-02

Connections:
+3V3: C2.1, C3.2, C4.2, C6.2, C8.1, C10.1 (+), C11.2, C12.2, C13.2, C17.2, C18.2, D1.A, D3.C, IC1.2 (VCC), IC3.1 (VDD), IC4.2 (OUT), IC4.4 (OUT), IC5.6 (VDDIO), IC5.8 (VDD), IC6.2 (3V3), J4.3, J5.3, R3.2, R6.1, R7.2, R8.2, R9.1, R11.2, R12.1, R13.2, SJ1.1, SJ3.3, U1.VDD, X1.1
+12V: IC2.IN+, J1.3, SJ2.1
A: IC8.15 (B4), J3.1, JP1.9
B: IC7.14 (B5), J3.2, JP1.10
BLUE1: IC8.11 (B8), JP1.3
BLUE2: IC7.11 (B8), JP1.7
BUZ: HA1.A, R15.1
C: IC7.13 (B6), J3.3, JP1.11
CLOCK: IC8.14 (B5), JP1.13
D: IC7.12 (B7), J3.4, JP1.12
E: IC8.16 (B3), JP1.8
EN: C1.2, IC6.3 (EN), J2.1, R6.2, RST.B
GND: B1.-, C1.1, C2.2, C3.1, C4.1, C5.2 (-), C6.1, C7.2, C8.2, C9.2, C10.2 (-), C11.1, C12.1, C13.1, C14.2, C15.2, C16.2, C17.1, C18.1, G1.-, G2.P"-" (-), HA1.C, IC1.5 (GND), IC1.6 (GND), IC1.7 (GND), IC1.8 (GND), IC1.9 (GND), IC1.10 (GND), IC1.11 (GND), IC1.12 (GND), IC1.13 (GND), IC2.IN-, IC2.OUT-, IC3.2 (ADDR), IC3.3 (GND), IC4.1 (GND), IC5.1 (GND), IC5.7 (GND), IC6.1 (GND), IC6.15 (GND), IC6.38 (GND), IC6.39 (GND), IC6.GND, IC6.PAD$1 (GND), IC6.PAD$4 (GND), IC6.PAD$5 (GND), IC6.PAD$7 (GND), IC6.PAD$8 (GND), IC6.PAD$9 (GND), IC7.10 (GND), IC7.19 (G), IC8.10 (GND), IC8.19 (G), J1.1, J2.4, J3.6, J4.4, J5.4, JP1.4, JP1.16, LED1.C, LED2.C, R1.1, R2.1, R10.2, RST.A, RST.SH0 (SH), S1.3 (1), S1.4 (1), S1.C, U1.GND, X1.4, X2.1
GREEN1: IC8.12 (B7), JP1.2
GREEN2: IC7.17 (B2), JP1.6
IO0: IC6.25 (IO0), J2.6, R11.1, S1.1 (2), S1.2
IO2: IC6.24 (IO2), IC6.48 (IO2), IC7.2 (A1), R10.1
IO4: IC6.26 (IO4), IC7.4 (A3)
IO5: IC6.29 (IO5), IC7.6 (A5)
IO12: IC6.14 (IO12), IC8.8 (A7)
IO13: IC6.16 (IO13), IC6.40 (IO13), IC8.9 (A8)
IO14: IC6.13 (IO14), IC8.7 (A6)
IO15: IC6.23 (IO15), IC6.47 (IO15), IC7.3 (A2)
IO16: IC6.27 (I16), IC7.5 (A4)
IO17: IC6.28 (I17)
IO18: IC6.30 (IO18), IC7.7 (A6)
IO19: IC6.31 (IO19), IC7.8 (A7)
IO21: IC6.33 (IO21), IC7.9 (A8)
IO25: IC6.10 (IO25), IC8.4 (A3)
IO26: IC6.11 (IO26), IC8.5 (A4)
IO27: IC6.12 (IO27), IC8.6 (A5)
IO32: IC6.8 (IO32), IC8.2 (A1)
IO33: IC6.9 (IO33), IC8.3 (A2)
IO34: IC1.3 (INT), IC6.6 (IO34), R8.1
IO35: IC6.7 (IO35), R9.2, X1.2
LATCH: IC8.18 (B1), JP1.14
LED: IC7.15 (B4), R14.2
unnamed: D1.C, D2.C, IC1.14 (VBAT)
unnamed: LED1.A, R13.1
unnamed: LED2.A, R14.1, S1.A
unnamed: C9.1, IC3.5 (DVI), R12.2
unnamed: IC1.1 (32KHZ), R7.1
unnamed: R4.1, R5.1, SJ1.2
unnamed: D3.A, J2.2
unnamed: B1.+, D2.A, G1.+, G2.P1"+" (+)
OE: IC8.17 (B2), JP1.15
RED1: IC7.16 (B3), JP1.1
RED2: IC8.13 (B6), JP1.5
RX3V3: IC6.34 (RXD0), J2.5
SCL: IC1.16 (SCL), IC3.6 (SCL), IC5.4 (SCK/SCL), IC6.36 (IO22), J4.1, J5.1, R4.2, U1.SCK
SDA: IC1.15 (SDA), IC3.4 (SDA), IC5.3 (SDI/SDA), IC6.37 (IO23), J4.2, J5.2, R5.2, U1.DATA
SVN: IC6.5 (SENSOR_VN), R1.2, R2.2, R3.1
SVP: IC6.4 (SENSOR_VP)
TX3V3: IC6.35 (TXD0), J2.3
VCC: C14.1, C15.1, C16.1, IC7.1 (DIR), IC7.20 (VCC), IC8.1 (DIR), IC8.20 (VCC), J3.5, SJ3.1
VIN: C5.1 (+), C7.1, IC2.OUT+, IC4.3 (IN), SJ2.2, SJ3.2, X2.2
_BUZ: IC7.18 (B1), R15.2

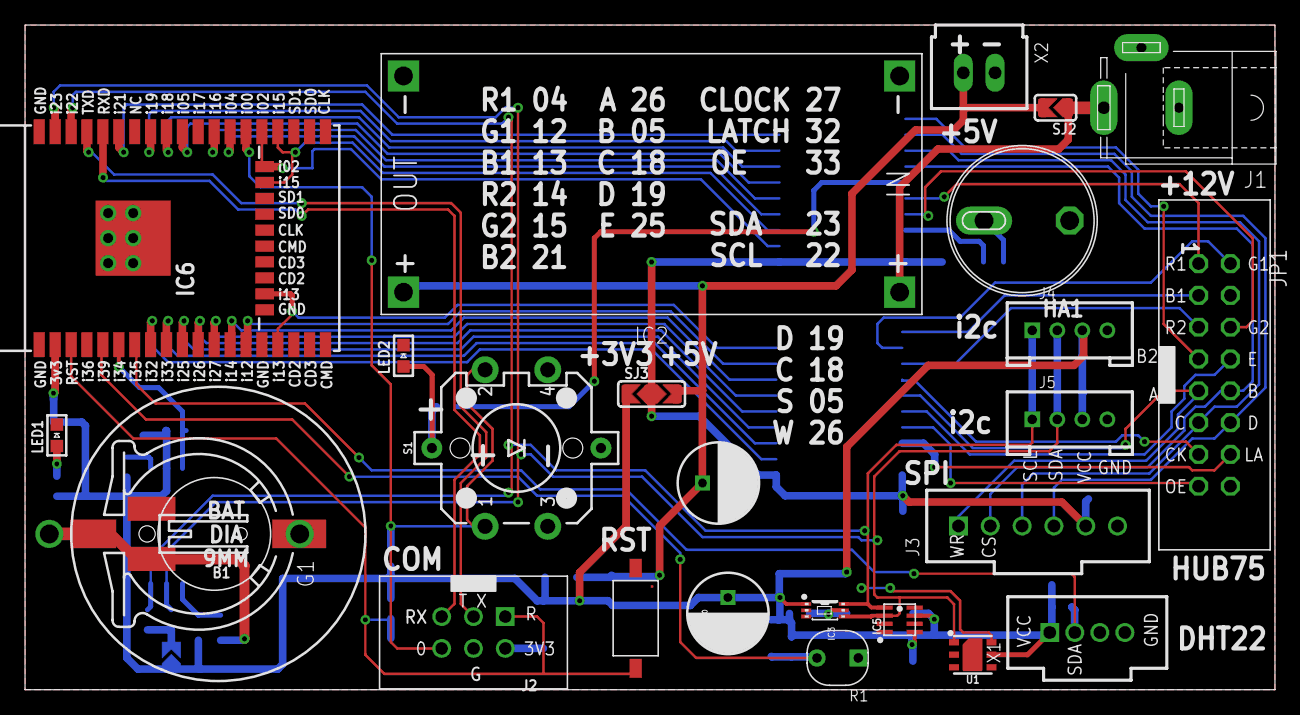
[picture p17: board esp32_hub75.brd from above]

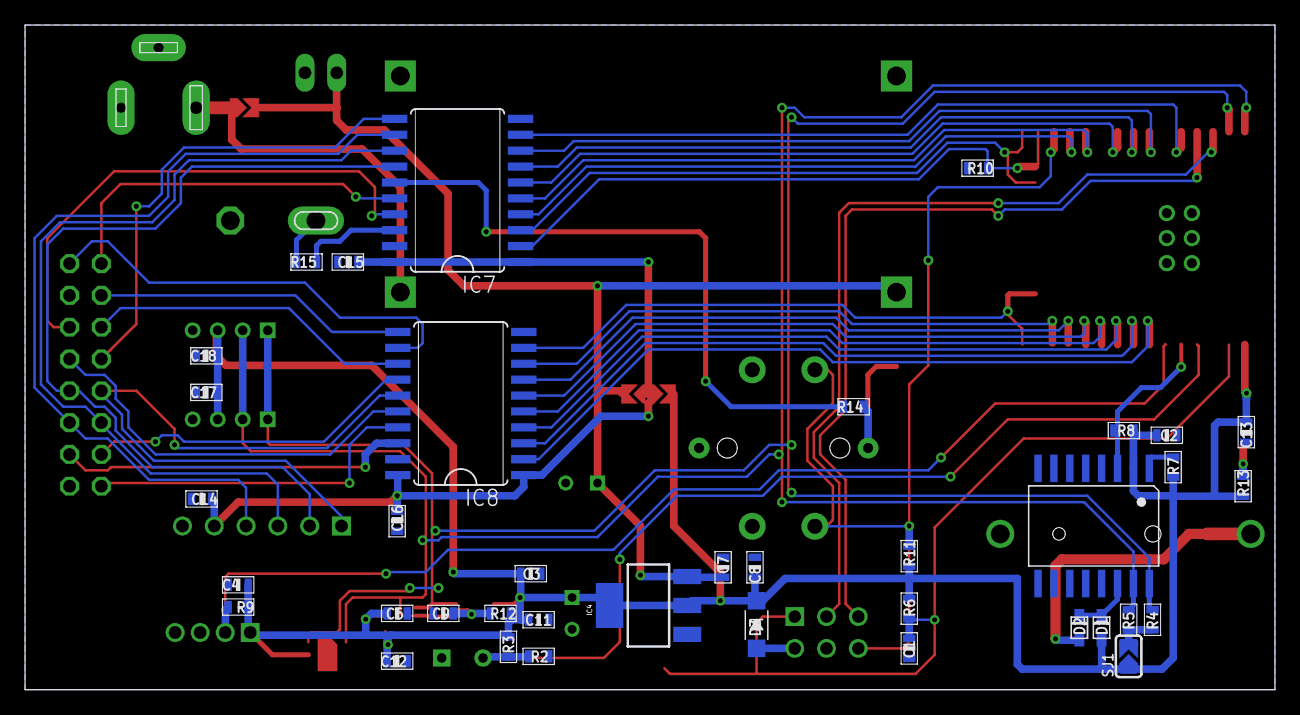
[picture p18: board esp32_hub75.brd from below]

Board: 2 copper layers, 99.8 x 53.1 mm, 64 parts (38 on the bottom side), 55 nets.

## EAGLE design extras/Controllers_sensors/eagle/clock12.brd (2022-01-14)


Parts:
C101, C102, C104, C105, C108, C111, C112: 10u; 0603-CAP
C103, C106, C107, C109: 0.1u; 0603-CAP
C110, C113, C114, C115: 1u; 0603-CAP
IC101: ESP32C3; ESP32C3-S
IC102: ESP32; ESP32-WROOVER/WROOM
IC103: ESP32C3-MODULE13U; ESP32C3-13U
IC104: ESP32S2; ESP-12K
J101, J106, J107: USB_MICRO-BFEMALE_SMT_; USB-B-MICRO-SMD_MY
J102, J103, J104, J105: COM; 2X03_SMT
J108, J111: HEADER-2X8; 2X8
J109, J110: HEADER-2X13; 2X13
R101, R103, R104: 100k; R0603
R102, R105, R106, R107: 10k; R0603
SJ101, SJ102: L/W; MICROBUILDER_SOLDERJUMPER_ARROW_NOPASTE_3
SW101, SW103, SW104, SW105: RST; MICROPUSH-BUT_TOP
SW102, SW106, SW107, SW108: PRG; MICROPUSH-BUT_TOP
U101, U102, U103: AP2112; SOT23-5

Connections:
1EN: C110.1, IC104.RST (EN), J104.1, J109.1, R102.1, SW101.B
1EN_P: R101.2, U101.3 (EN)
1IO0: IC104.I00, J104.6, J109.2, SW102.B
1IO1: IC104.I01, J109.9
1IO2: IC104.I02, J109.10
1IO3: IC104.I03, J109.11
1IO4: IC104.I04, J109.12
1IO5: IC104.I05
1IO6: IC104.I06
1IO7: IC104.I07
1IO8: IC104.I08
1IO9: IC104.I09, J109.26
1IO10: IC104.I10, J109.25
1IO11: IC104.I11, J109.24
1IO12: IC104.I12, J109.23
1IO13: IC104.I13, J109.22
1IO14: IC104.I14, J109.21
1IO15: IC104.I15, J109.20
1IO16: IC104.I16, J109.19
1IO17: IC104.I17, J109.7
1IO18: IC104.I18, J109.8
1IO19: IC104.I19, J101.D-
1IO20: IC104.I20, J101.D+
1IO21: IC104.I21, J109.18
1IO26: IC104.I26, J109.17
1IO33: IC104.I33, J109.14
1IO34: IC104.I34, J109.13
1IO35: IC104.I35, J109.16
1IO36: IC104.I36, J109.15
1IO37: IC104.I37, J109.5
1IO38: IC104.I38
1IO39: IC104.I39
1IO40: IC104.I40
1IO41: IC104.I41
1IO42: IC104.I42
1IO45: IC104.I45
1IO46: IC104.I46
1RX0: IC104.RX, J104.5
1TX0: IC104.TX, J104.3
2D+: IC103.IO19, J107.D+
2D-: IC103.IO18, J107.D-
2EN: C115.1, IC103.EN, J103.1, J108.1, R107.1, SW105.B
2EN_P: R104.2, U103.3 (EN)
2IO0: IC103.IO0, J108.8
2IO1: IC103.IO1, J108.7
2IO2: IC103.IO2, J108.5
2IO3: IC103.IO3, J108.12
2IO4: IC103.IO4, SJ101.1
2IO5: IC103.IO5, J108.9
2IO6: IC103.IO6, J108.10
2IO7: IC103.IO7, J108.16
2IO8: IC103.IO8, J108.14
2IO9: IC103.IO9, J103.6, J108.2, SW108.B
2IO10: IC103.IO10, J108.15
2RX0: IC103.RX0, J103.5
2TX0: IC103.TX0, J103.3
3D+: IC101.31 (IO19), J106.D+
3D-: IC101.30 (IO18), J106.D-
3EN: C114.1, IC101.3 (EN), J102.1, J111.1, R106.1, SW104.B
3EN_P: R103.2, U102.3 (EN)
3IO0: IC101.5 (IO0), J111.8
3IO1: IC101.6 (IO1), J111.7
3IO2: IC101.7 (IO2), J111.5
3IO3: IC101.8 (IO3), J111.12
3IO4: IC101.9 (IO4), SJ102.1
3IO5: IC101.10 (IO5), J111.9
3IO6: IC101.11 (IO6), J111.10
3IO7: IC101.12 (IO7), J111.16
3IO8: IC101.13 (IO8), J111.14
3IO9: IC101.25 (IO9), J102.6, J111.2, SW107.B
3IO10: IC101.14 (IO10), J111.15
3RX0: IC101.34 (RX0), J102.5
3TX0: IC101.35 (TX0), J102.3
4EN: C113.1, IC102.3 (EN), J105.1, J110.1, R105.1, SW103.B
4IO0: IC102.25 (IO0), J105.6, J110.2, SW106.B
4IO2: IC102.24 (IO2), IC102.48 (IO2), J110.12
4IO4: IC102.26 (IO4), J110.19
4IO5: IC102.29 (IO5), J110.14
4IO12: IC102.14 (IO12), J110.20
4IO13: IC102.16 (IO13), IC102.40 (IO13), J110.21
4IO14: IC102.13 (IO14), J110.22
4IO15: IC102.23 (IO15), IC102.47 (IO15), J110.23
4IO16: IC102.27 (I16), J110.11
4IO17: IC102.28 (I17), J110.8
4IO18: IC102.30 (IO18), J110.15
4IO19: IC102.31 (IO19), J110.16
4IO21: IC102.33 (IO21), J110.24
4IO22: IC102.36 (IO22), J110.10
4IO23: IC102.37 (IO23), J110.9
4IO25: IC102.10 (IO25), J110.17
4IO26: IC102.11 (IO26), J110.13
4IO27: IC102.12 (IO27), J110.25
4IO32: IC102.8 (IO32), J110.26
4IO33: IC102.9 (IO33), J110.18
4IO34: IC102.6 (IO34), J110.5
4IO35: IC102.7 (IO35), J110.7
4RX0: IC102.34 (RXD0), J105.5
4SVN: IC102.5 (SENSOR_VN)
4SVP: IC102.4 (SENSOR_VP)
4TX0: IC102.35 (TXD0), J105.3
+3V3_1: C105.2, C109.2, IC104.VCC (3V3), J104.2, J109.4, R102.2, U101.5 (OUT)
+3V3_2: C107.2, C108.2, IC103.3V3 (VCC), J103.2, J108.4, R107.2, U103.5 (OUT)
+3V3_3: C103.2, C104.2, IC101.2 (VCC), J102.2, J111.4, R106.2, U102.5 (OUT)
+3V3_4: C102.2, C106.2, IC102.2 (3V3), J105.2, J110.4, R105.2
+5V_1: C101.1, J101.VBUS, J109.6, R101.1, U101.1 (IN)
+5V_2: C112.1, J107.VBUS, J108.6, R104.1, U103.1 (IN)
+5V_3: C111.1, J106.VBUS, J111.6, R103.1, U102.1 (IN)
+5V_4: J110.6
GND: C101.2, C102.1, C103.1, C104.1, C105.1, C106.1, C107.1, C108.1, C109.1, C110.2, C111.2, C112.2, C113.2, C114.2, C115.2, IC101.1 (GND), IC101.38 (GND), IC101.39 (GND), IC102.1 (GND), IC102.15 (GND), IC102.38 (GND), IC102.39 (GND), IC102.GND, IC102.PAD$1 (GND), IC102.PAD$4 (GND), IC102.PAD$5 (GND), IC102.PAD$7 (GND), IC102.PAD$8 (GND), IC102.PAD$9 (GND), IC103.GND, IC104.GND1 (GND), IC104.GND2 (GND), IC104.GND3 (GND), IC104.PAD0 (GND), IC104.PAD1 (GND), IC104.PAD2 (GND), IC104.PAD3 (GND), IC104.PAD4 (GND), IC104.PAD5 (GND), IC104.PAD6 (GND), IC104.PAD7 (GND), IC104.PAD8 (GND), J101.GND, J101.SH@1 (SHIELD), J101.SH@2 (SHIELD), J101.SH@3 (SHIELD), J101.SH@4 (SHIELD), J101.SH@5 (SHIELD), J101.SH@6 (SHIELD), J102.4, J103.4, J104.4, J105.4, J106.GND, J106.SH@1 (SHIELD), J106.SH@2 (SHIELD), J106.SH@3 (SHIELD), J106.SH@4 (SHIELD), J106.SH@5 (SHIELD), J106.SH@6 (SHIELD), J107.GND, J107.SH@1 (SHIELD), J107.SH@2 (SHIELD), J107.SH@3 (SHIELD), J107.SH@4 (SHIELD), J107.SH@5 (SHIELD), J107.SH@6 (SHIELD), J108.3, J109.3, J110.3, J111.3, SW101.A, SW101.SH0 (SH), SW102.A, SW102.SH0 (SH), SW103.A, SW103.SH0 (SH), SW104.A, SW104.SH0 (SH), SW105.A, SW105.SH0 (SH), SW106.A, SW106.SH0 (SH), SW107.A, SW107.SH0 (SH), SW108.A, SW108.SH0 (SH), U101.2 (GND), U102.2 (GND), U103.2 (GND); also elsewhere on the board
IN2_A: J108.13, SJ101.2
IN2_LED: J108.11, SJ101.3
IN3_A: J111.13, SJ102.2
IN3_LED: J111.11, SJ102.3

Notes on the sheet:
600mA out 6V max in


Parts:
C201, C203, C207, C208, C211, C212: 0.1u; 0603-CAP
C202, C204, C209: 1u; 0603-CAP
C205, C206, C210: 10u; 0603-CAP
D201: 1N5819; SOD123
D202: CRG; LED-0603
G201: BATTERY-LI-MH12210
IC201: AP2112; SOT23-5
IC202: SI7021; DFN-6-3X3-SI7021
IC203: MCP73831; SOT23-5
IC204: BME280; LGA-8-2.5X2.5
IC205: BH1750; WSOF6L
J201: USB_C16PIN; USB-C-16P
J202: FR; 1X03
J203: HEADER-2X5; 2X05
J204: DHT22; 70543-04
J205: +5V; 70543-02
J206: AM2320; 70543-04
J207: LiPo; JST-2-SMD
Q201: 2301; SOT23-3@1
R201, R202: 47k; R0603
R203: 5.1k; R0603
R204, R210, R212: 10k; R0603
R205: 27k; R0603
R206, R207: 100k; R0603
R208, R209, R215: 1k; R0603
R211: 2k; R0603
R213, R214: 3k3; R0603
SJ201: PR NEG/POS; MICROBUILDER_SOLDERJUMPER_ARROW_NOPASTE_3
SJ202: i2c_pullup; MICROBUILDER_SOLDERJUMPER_ARROW_NOPASTE
SJ203: 1/5; MICROBUILDER_SOLDERJUMPER_ARROW_NOPASTE_3
SW201: MICROSWITCH-BUTTONANGLE; MICROPUSH-BUT_ANG
SW202: BAT ON; SWITCH-SMD-L6.7X2.7X3.2MM

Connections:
+3V3_S: C201.1, C203.2, C204.1, C205.1, C207.2, C208.2, C211.2, IC201.5 (OUT), IC202.VDD, IC204.6 (VDDIO), IC204.8 (VDD), IC205.1 (VDD), J203.4, J204.1, J206.1, R202.2, R208.1, R210.2, R215.1, SJ202.1
+5V: C202.1, D201.C, IC201.1 (IN), Q201.2 (S), R207.1
+5V_S: C206.1, D201.A, IC203.4 (VIN), J201.VBUS1 (VBUS), J201.VBUS2 (VBUS), J203.6, J205.2, Q201.1 (G), R204.2, R209.1
CHG: D202.C, IC203.1 (STAT)
EN_S: C209.1, J203.1, R210.1, SW201.A
EN_S_P: IC201.3 (EN), R207.2
GND: C201.2, C202.2, C203.1, C204.2, C205.2, C206.2, C207.1, C208.1, C209.2, C210.2, C211.1, C212.2, G201.BAT-, IC201.2 (GND), IC202.GND, IC203.2 (VSS), IC204.1 (GND), IC204.7 (GND), IC205.2 (ADDR), IC205.3 (GND), J201.GND, J201.GND2 (GND), J201.SHLD1 (SHLD), J201.SHLD2 (SHLD), J201.SHLD3 (SHLD), J201.SHLD4 (SHLD), J201.SHLD5 (SHLD), J201.SHLD6 (SHLD), J201.SHLD7 (SHLD), J201.SHLD8 (SHLD), J203.3, J204.4, J205.1, J206.3, J207.1 (2), R201.1, R203.1, R204.1, R205.1, R211.1, R212.2, SW201.B, SW201.SH0 (SH), SW201.SH3 (SH), SW202.SS1 (GND1), SW202.SS2 (GND1), SW202.SS3 (GND1), SW202.SS4 (GND1); also elsewhere on the board
I2C_SCL_S: IC202.SCK, IC204.4 (SCK/SCL), IC205.6 (SCL), J203.10, J206.4, R213.2
I2C_SDA_S: IC202.DATA, IC204.3 (SDI/SDA), IC205.4 (SDA), J203.9, J206.2, R214.2
IN_DHT_S: J203.8, J204.2, R208.2
unnamed: D202.A, R209.2
unnamed: R211.2, SJ203.2
unnamed: R213.1, R214.1, SJ202.2
unnamed: J203.5, R205.2, R206.1
unnamed: G201.BAT+, J207.2 (1), SW202.A
unnamed: J202.3, R202.1, SJ201.3
unnamed: IC203.5 (PROG), SJ203.1
unnamed: J202.1, R201.2, SJ201.2
unnamed: R212.1, SJ203.3
unnamed: J201.A5 (CC1), J201.B5 (CC2), R203.2
unnamed: C212.1, IC205.5 (DVI), R215.2
PHOTO_RES: J202.2, J203.7, SJ201.1
V_BAT: C210.1, IC203.3 (VBAT), Q201.3 (D), R206.2, SW202.B, SW202.COM

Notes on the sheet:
V_BATT should be a single- cell LiPo battery.
Charge current: I_CHG = 1000 / R_PROG R_PROG=2k : I_CHG=500mA (DEFAULT) R_PROG=10k : I_CHG=100mA
Voltage Regulator and Battery Charger
Lithium-Polymer Battery Charger (1-cell)
600mA out 6V max in
V_USB - 6V MAX V_BATT - Single Cell (4.2V MAX)
100mA
500mA


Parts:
C301, C304: 22u; 0603-CAP
C302, C303, C307: 0.1u; 0603-CAP
C305, C306: 1u; 0603-CAP
D301, D302: IN5819; SOD123
IC301: AP2112; SOT23-5
IC302: CP2102; QFN28G_0.5-5X5MM
J301: PROG; JST-SH-8-SMT-1MM
J302: USB_C16PIN; USB-C-16P
J303: +5V; 70543-02
J304: COM1; 2X03_1.27MM_SMT
J305: COM2; 2X03_SMT
Q301: SMD-MOSFET-DUAL-N-CH-30V-2.9A-SI5902DC-T1-E3(1206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; SOT363_PHILIPS
R301: 100k; R0603
R302: 5.1k; R0603
R303, R304, R305: 10k; R0603
R306: 4.7k; R0603
R307, R308: 2k; R0603
SW301: RST; MICROPUSH-BUT_TOP
SW302: PRG; MICROPUSH-BUT_TOP

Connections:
+3V3: C304.1, C307.1, D302.A, IC301.5 (OUT), R303.1, R304.2
+3V3_CP: C303.2, C306.2, IC302.6 (VDD), R306.2
D+: IC302.4 (D+), J302.A6 (D+), J302.B6 (D+)
D-: IC302.5 (D-), J302.A7 (D-), J302.B7 (D-)
DTR: IC302.28 (DTR), Q301.1 (S), R308.1
EN: C305.2, J301.P$1 (1), J304.1, J305.1, Q301.3 (D), R303.2, SW301.A
EN_S_P1: IC301.3 (EN), R301.2
GND: C301.2, C302.2, C303.1, C304.2, C305.1, C306.1, C307.2, IC301.2 (GND), IC302.3 (GND), IC302.29 (GND), IC302.HG1 (GND), IC302.HG2 (GND), IC302.HG3 (GND), IC302.HG4 (GND), IC302.HG5 (GND), J301.P$5 (5), J301.P$8 (8), J301.P$9 (GND1), J301.P$10 (GND2), J302.GND, J302.GND2 (GND), J302.SHLD1 (SHLD), J302.SHLD2 (SHLD), J302.SHLD3 (SHLD), J302.SHLD4 (SHLD), J302.SHLD5 (SHLD), J302.SHLD6 (SHLD), J302.SHLD7 (SHLD), J302.SHLD8 (SHLD), J303.1, J304.4, J305.4, R302.1, R305.2, SW301.B, SW301.SH0 (SH), SW302.B, SW302.SH0 (SH); also elsewhere on the board
GPIO0: J301.P$2 (2), J304.6, J305.6, Q301.6 (D), R304.1, SW302.A
unnamed: D301.C, J301.P$6 (6)
unnamed: J302.A5 (CC1), J302.B5 (CC2), R302.2
unnamed: Q301.2 (G), R307.2
unnamed: Q301.5 (G), R308.2
unnamed: IC302.11 (!SUSPEND), R305.1
unnamed: IC302.9 (!RST), R306.1
RTS: IC302.24 (RTS), Q301.4 (S), R307.1
RX: IC302.26 (TXD), J301.P$3 (3), J304.5, J305.5
TX: IC302.25 (RXD), J301.P$4 (4), J304.3, J305.3
VBUS: C301.1, C302.1, D301.A, IC301.1 (IN), IC302.7 (REGIN), IC302.8 (VBUS), J302.VBUS1 (VBUS), J302.VBUS2 (VBUS), J303.2, R301.1
VCON: D302.C, J301.P$7 (7), J304.2, J305.2

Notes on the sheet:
600mA out 6V max in



Board: 2 copper layers, 73.0 x 90.0 mm, 125 parts (33 on the bottom side), 140 nets.

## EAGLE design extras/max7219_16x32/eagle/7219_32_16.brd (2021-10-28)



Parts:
C101, C102, C105, C106, C109, C110, C113, C114: 10u; EIA3216
C103, C104, C107, C108, C111, C112, C115, C116: 0.1u; 0603-CAP
IC101, IC102, IC103, IC104, IC105, IC106, IC107, IC108: MAX7219; SO24L
J101: IN; 70543-05
J102: OUT; 70543-05
LED101, LED102, LED103, LED104, LED105, LED106, LED107, LED108: 1088AS; SEGMENT_BL-M12A881UR
R101, R102, R105, R106, R109, R110, R113, R114: 10k; R0603
R103, R104, R107, R108, R111, R112, R115, R116: 27k; R0603

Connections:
1A: IC101.14 (SEGA), LED101.13 (A1)
1B: IC101.16 (SEGB), LED101.3 (A2)
1C: IC101.20 (SEGC), LED101.4 (A3)
1D: IC101.23 (SEGD), LED101.10 (A4)
1D0: IC101.2 (DIG0), LED101.9 (K1)
1D1: IC101.11 (DIG1), LED101.14 (K2)
1D2: IC101.6 (DIG2), LED101.8 (K3)
1D3: IC101.7 (DIG3), LED101.12 (K4)
1D4: IC101.3 (DIG4), LED101.1 (K5)
1D5: IC101.10 (DIG5), LED101.7 (K6)
1D6: IC101.5 (DIG6), LED101.2 (K7)
1D7: IC101.8 (DIG7), LED101.5 (K8)
1DP: IC101.22 (SEGDP), LED101.16 (A8)
1E: IC101.21 (SEGE), LED101.6 (A5)
1F: IC101.15 (SEGF), LED101.11 (A6)
1G: IC101.17 (SEGG), LED101.15 (A7)
2A: IC103.14 (SEGA), LED103.13 (A1)
2B: IC103.16 (SEGB), LED103.3 (A2)
2C: IC103.20 (SEGC), LED103.4 (A3)
2D: IC103.23 (SEGD), LED103.10 (A4)
2D0: IC103.2 (DIG0), LED103.9 (K1)
2D1: IC103.11 (DIG1), LED103.14 (K2)
2D2: IC103.6 (DIG2), LED103.8 (K3)
2D3: IC103.7 (DIG3), LED103.12 (K4)
2D4: IC103.3 (DIG4), LED103.1 (K5)
2D5: IC103.10 (DIG5), LED103.7 (K6)
2D6: IC103.5 (DIG6), LED103.2 (K7)
2D7: IC103.8 (DIG7), LED103.5 (K8)
2DP: IC103.22 (SEGDP), LED103.16 (A8)
2E: IC103.21 (SEGE), LED103.6 (A5)
2F: IC103.15 (SEGF), LED103.11 (A6)
2G: IC103.17 (SEGG), LED103.15 (A7)
3A: IC105.14 (SEGA), LED105.13 (A1)
3B: IC105.16 (SEGB), LED105.3 (A2)
3C: IC105.20 (SEGC), LED105.4 (A3)
3D: IC105.23 (SEGD), LED105.10 (A4)
3D0: IC105.2 (DIG0), LED105.9 (K1)
3D1: IC105.11 (DIG1), LED105.14 (K2)
3D2: IC105.6 (DIG2), LED105.8 (K3)
3D3: IC105.7 (DIG3), LED105.12 (K4)
3D4: IC105.3 (DIG4), LED105.1 (K5)
3D5: IC105.10 (DIG5), LED105.7 (K6)
3D6: IC105.5 (DIG6), LED105.2 (K7)
3D7: IC105.8 (DIG7), LED105.5 (K8)
3DP: IC105.22 (SEGDP), LED105.16 (A8)
3E: IC105.21 (SEGE), LED105.6 (A5)
3F: IC105.15 (SEGF), LED105.11 (A6)
3G: IC105.17 (SEGG), LED105.15 (A7)
4A: IC107.14 (SEGA), LED107.13 (A1)
4B: IC107.16 (SEGB), LED107.3 (A2)
4C: IC107.20 (SEGC), LED107.4 (A3)
4D: IC107.23 (SEGD), LED107.10 (A4)
4D0: IC107.2 (DIG0), LED107.9 (K1)
4D1: IC107.11 (DIG1), LED107.14 (K2)
4D2: IC107.6 (DIG2), LED107.8 (K3)
4D3: IC107.7 (DIG3), LED107.12 (K4)
4D4: IC107.3 (DIG4), LED107.1 (K5)
4D5: IC107.10 (DIG5), LED107.7 (K6)
4D6: IC107.5 (DIG6), LED107.2 (K7)
4D7: IC107.8 (DIG7), LED107.5 (K8)
4DP: IC107.22 (SEGDP), LED107.16 (A8)
4E: IC107.21 (SEGE), LED107.6 (A5)
4F: IC107.15 (SEGF), LED107.11 (A6)
4G: IC107.17 (SEGG), LED107.15 (A7)
5A: IC102.14 (SEGA), LED102.13 (A1)
5B: IC102.16 (SEGB), LED102.3 (A2)
5C: IC102.20 (SEGC), LED102.4 (A3)
5D: IC102.23 (SEGD), LED102.10 (A4)
5D0: IC102.2 (DIG0), LED102.9 (K1)
5D1: IC102.11 (DIG1), LED102.14 (K2)
5D2: IC102.6 (DIG2), LED102.8 (K3)
5D3: IC102.7 (DIG3), LED102.12 (K4)
5D4: IC102.3 (DIG4), LED102.1 (K5)
5D5: IC102.10 (DIG5), LED102.7 (K6)
5D6: IC102.5 (DIG6), LED102.2 (K7)
5D7: IC102.8 (DIG7), LED102.5 (K8)
5DP: IC102.22 (SEGDP), LED102.16 (A8)
5E: IC102.21 (SEGE), LED102.6 (A5)
5F: IC102.15 (SEGF), LED102.11 (A6)
5G: IC102.17 (SEGG), LED102.15 (A7)
6A: IC104.14 (SEGA), LED104.13 (A1)
6B: IC104.16 (SEGB), LED104.3 (A2)
6C: IC104.20 (SEGC), LED104.4 (A3)
6D: IC104.23 (SEGD), LED104.10 (A4)
6D0: IC104.2 (DIG0), LED104.9 (K1)
6D1: IC104.11 (DIG1), LED104.14 (K2)
6D2: IC104.6 (DIG2), LED104.8 (K3)
6D3: IC104.7 (DIG3), LED104.12 (K4)
6D4: IC104.3 (DIG4), LED104.1 (K5)
6D5: IC104.10 (DIG5), LED104.7 (K6)
6D6: IC104.5 (DIG6), LED104.2 (K7)
6D7: IC104.8 (DIG7), LED104.5 (K8)
6DP: IC104.22 (SEGDP), LED104.16 (A8)
6E: IC104.21 (SEGE), LED104.6 (A5)
6F: IC104.15 (SEGF), LED104.11 (A6)
6G: IC104.17 (SEGG), LED104.15 (A7)
7A: IC106.14 (SEGA), LED106.13 (A1)
7B: IC106.16 (SEGB), LED106.3 (A2)
7C: IC106.20 (SEGC), LED106.4 (A3)
7D: IC106.23 (SEGD), LED106.10 (A4)
7D0: IC106.2 (DIG0), LED106.9 (K1)
7D1: IC106.11 (DIG1), LED106.14 (K2)
7D2: IC106.6 (DIG2), LED106.8 (K3)
7D3: IC106.7 (DIG3), LED106.12 (K4)
7D4: IC106.3 (DIG4), LED106.1 (K5)
7D5: IC106.10 (DIG5), LED106.7 (K6)
7D6: IC106.5 (DIG6), LED106.2 (K7)
7D7: IC106.8 (DIG7), LED106.5 (K8)
7DP: IC106.22 (SEGDP), LED106.16 (A8)
7E: IC106.21 (SEGE), LED106.6 (A5)
7F: IC106.15 (SEGF), LED106.11 (A6)
7G: IC106.17 (SEGG), LED106.15 (A7)
8A: IC108.14 (SEGA), LED108.13 (A1)
8B: IC108.16 (SEGB), LED108.3 (A2)
8C: IC108.20 (SEGC), LED108.4 (A3)
8D: IC108.23 (SEGD), LED108.10 (A4)
8D0: IC108.2 (DIG0), LED108.9 (K1)
8D1: IC108.11 (DIG1), LED108.14 (K2)
8D2: IC108.6 (DIG2), LED108.8 (K3)
8D3: IC108.7 (DIG3), LED108.12 (K4)
8D4: IC108.3 (DIG4), LED108.1 (K5)
8D5: IC108.10 (DIG5), LED108.7 (K6)
8D6: IC108.5 (DIG6), LED108.2 (K7)
8D7: IC108.8 (DIG7), LED108.5 (K8)
8DP: IC108.22 (SEGDP), LED108.16 (A8)
8E: IC108.21 (SEGE), LED108.6 (A5)
8F: IC108.15 (SEGF), LED108.11 (A6)
8G: IC108.17 (SEGG), LED108.15 (A7)
+5V: C101.A (+), C102.A (+), C103.1, C104.1, C105.A (+), C106.A (+), C107.1, C108.1, C109.A (+), C110.A (+), C111.1, C112.1, C113.A (+), C114.A (+), C115.1, C116.1, IC101.19 (VCC), IC102.19 (VCC), IC103.19 (VCC), IC104.19 (VCC), IC105.19 (VCC), IC106.19 (VCC), IC107.19 (VCC), IC108.19 (VCC), J101.4, J102.4, R103.1, R104.1, R107.1, R108.1, R111.1, R112.1, R115.1, R116.1; also elsewhere on the board
CLK: IC101.13 (CLK), IC102.13 (CLK), IC103.13 (CLK), IC104.13 (CLK), IC105.13 (CLK), IC106.13 (CLK), IC107.13 (CLK), IC108.13 (CLK), J101.2, J102.2; also elsewhere on the board
DIN: IC101.1 (DIN), J101.3; also elsewhere on the board
DOUT1: IC101.24 (DOUT), IC103.1 (DIN)
DOUT2: IC103.24 (DOUT), IC105.1 (DIN)
DOUT3: IC105.24 (DOUT), IC107.1 (DIN)
DOUT4: IC102.1 (DIN), IC107.24 (DOUT)
DOUT5: IC102.24 (DOUT), IC104.1 (DIN)
DOUT6: IC104.24 (DOUT), IC106.1 (DIN)
DOUT7: IC106.24 (DOUT), IC108.1 (DIN)
DOUT8: IC108.24 (DOUT), J102.3
GND: C101.C (-), C102.C (-), C103.2, C104.2, C105.C (-), C106.C (-), C107.2, C108.2, C109.C (-), C110.C (-), C111.2, C112.2, C113.C (-), C114.C (-), C115.2, C116.2, IC101.4 (GND), IC101.9 (GND), IC102.4 (GND), IC102.9 (GND), IC103.4 (GND), IC103.9 (GND), IC104.4 (GND), IC104.9 (GND), IC105.4 (GND), IC105.9 (GND), IC106.4 (GND), IC106.9 (GND), IC107.4 (GND), IC107.9 (GND), IC108.4 (GND), IC108.9 (GND), J101.5, J102.5, R101.1, R102.1, R105.1, R106.1, R109.1, R110.1, R113.1, R114.1; also elsewhere on the board
ISET1: IC101.18 (ISET), R103.2
ISET2: IC103.18 (ISET), R107.2
ISET3: IC105.18 (ISET), R111.2
ISET4: IC107.18 (ISET), R115.2
ISET5: IC102.18 (ISET), R104.2
ISET6: IC104.18 (ISET), R108.2
ISET7: IC106.18 (ISET), R112.2
ISET8: IC108.18 (ISET), R116.2
LOAD: IC101.12 (LOAD), IC102.12 (LOAD), IC103.12 (LOAD), IC104.12 (LOAD), IC105.12 (LOAD), IC106.12 (LOAD), IC107.12 (LOAD), IC108.12 (LOAD), J101.1, J102.1, R101.2, R102.2, R105.2, R106.2, R109.2, R110.2, R113.2, R114.2; also elsewhere on the board


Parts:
C201: 10u; EIA3216
C202: 0.1u; 0603-CAP
IC201: MAX7219; SO24L
J201: IN; 70543-05
LED201: ALS318A; АЛС318А
R201: 10k; R0603
R202: 27k; R0603

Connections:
9A: IC201.14 (SEGA), LED201.6
9B: IC201.16 (SEGB), LED201.14
9C: IC201.20 (SEGC), LED201.2
9D: IC201.23 (SEGD), LED201.10
9D0: IC201.2 (DIG0), LED201.3
9D1: IC201.11 (DIG1), LED201.5
9D2: IC201.6 (DIG2), LED201.7
9D3: IC201.7 (DIG3), LED201.9
9D4: IC201.3 (DIG4), LED201.11
9D5: IC201.10 (DIG5), LED201.13
9D6: IC201.5 (DIG6), LED201.15
9D7: IC201.8 (DIG7), LED201.17
9DP: IC201.22 (SEGDP), LED201.4
9E: IC201.21 (SEGE), LED201.8
9F: IC201.15 (SEGF), LED201.16
9G: IC201.17 (SEGG), LED201.12
+5V: C201.A (+), C202.1, IC201.19 (VCC), J201.4, R202.1; also elsewhere on the board
CLK: IC201.13 (CLK), J201.2; also elsewhere on the board
DIN: IC201.1 (DIN), J201.3; also elsewhere on the board
DOUT9: IC201.24 (DOUT)
GND: C201.C (-), C202.2, IC201.4 (GND), IC201.9 (GND), J201.5, R201.1; also elsewhere on the board
ISET9: IC201.18 (ISET), R202.2
LOAD: IC201.12 (LOAD), J201.1, R201.2; also elsewhere on the board


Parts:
B301: CR2032
C301, C309: 1u; 0603-CAP
C302, C305: 22u; 0603-CAP
C303, C304, C306, C307, C310, C311: 0.1u; 0603-CAP
C308: 10u; 0603-CAP
D301: IN5819; SOD123
D302, D303: 1N4148; SOD-323F
HA301: BUZZER; PBUZ_12X7.5
IC301: ESP12F; ESP12-SMD
IC302: DS3231W; SO16W
IC303: LD1117; SOT223
IC304: BH1750; WSOF6L
IC305: BME280; LGA-8-2.5X2.5
IC306: 74AC245DW; SO20W
J301: COM; 2X03_1.27MM_SMT
J302: Vin; 1X02
J303, J304: 4P-2.0; HW4-2.0
R301: 10K; SNR2-3.0
R302: 100k; R0603
R303: 220k; R0603
R304, R305, R308, R309, R310, R311: 10k; R0603
R306, R307: 4.7k; R0603
R312: 1k; R0603
R313: 2k; R0603
S301: SW1; TACTILE_SWITCH_LED_PTH_12MM_KIT
SJ301: i2c_pullup; MICROBUILDER_SOLDERJUMPER_ARROW_NOPASTE
SJ302: MICROBUILDER_SOLDERJUMPER3; MICROBUILDER_SOLDERJUMPER_ARROW_NOPASTE_3
SW301: RST; MICROPUSH-BUT_TOP
U301: SI7021; DFN-6-3X3-SI7021
X301: DSP; 70543-06

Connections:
+3V3: C302.1, C303.1, C304.2, C307.2, C310.2, C311.2, D301.C, D302.A, IC301.VCC, IC302.2 (VCC), IC303.2 (OUT), IC303.4 (OUT), IC304.1 (VDD), IC305.6 (VDDIO), IC305.8 (VDD), J303.3, J304.3, R303.2, R304.2, R305.1, R306.2, R307.2, R309.2, R312.1, SJ301.1, SJ302.2, U301.VDD; also elsewhere on the board
ADC: IC301.ADC, R301.2, R302.2, R303.1
BUZ: C308.1, IC306.18 (B1)
CLK: IC306.14 (B5), X301.3; also elsewhere on the board
DIN: IC306.13 (B6), X301.4; also elsewhere on the board
EN: C301.2, IC301.RESET, J301.1, R305.2, SW301.B; also elsewhere on the board
GND: B301.-, C301.1, C302.2, C303.2, C304.1, C305.2, C306.2, C307.1, C309.2, C310.1, C311.1, HA301.C, IC301.GND, IC302.5 (GND), IC302.6 (GND), IC302.7 (GND), IC302.8 (GND), IC302.9 (GND), IC302.10 (GND), IC302.11 (GND), IC302.12 (GND), IC302.13 (GND), IC303.1 (GND), IC304.2 (ADDR), IC304.3 (GND), IC305.1 (GND), IC305.7 (GND), IC306.10 (GND), IC306.19 (G), J301.4, J302.1, J303.4, J304.4, R301.1, R302.1, R308.1, S301.3 (1), S301.4 (1), S301.C, SW301.A, SW301.SH0 (SH), U301.GND, X301.6; also elsewhere on the board
GPIO0: IC301.GPIO0, J301.6, R309.1, S301.1 (2), S301.2; also elsewhere on the board
GPIO2: IC301.GPIO2, IC306.3 (A2), IC306.4 (A3)
GPIO12: IC301.GPIO12, IC302.3 (INT), R307.1
GPIO13: IC301.GPIO13, IC306.7 (A6)
GPIO14: IC301.GPIO14, IC306.6 (A5)
GPIO15: IC301.GPIO15, IC306.2 (A1), R308.2
GPIO16: IC301.GPIO16, IC306.5 (A4)
LED: IC306.17 (B2), R313.1
LOAD: IC306.15 (B4), X301.2; also elsewhere on the board
unnamed: D302.C, D303.C, IC302.14 (VBAT)
unnamed: R313.2, S301.A
unnamed: IC301.CH_PD, R304.1
unnamed: C308.2, HA301.A
unnamed: C309.1, IC304.5 (DVI), R312.2
unnamed: IC302.1 (32KHZ), R306.1
unnamed: R310.1, R311.1, SJ301.2
unnamed: D301.A, J301.2
unnamed: B301.+, D303.A
RX: IC301.RXD0 (RX), J301.5; also elsewhere on the board
SCL: IC301.GPIO5, IC302.16 (SCL), IC304.6 (SCL), IC305.4 (SCK/SCL), J303.1, J304.1, R311.2, U301.SCK
SDA: IC301.GPIO4, IC302.15 (SDA), IC304.4 (SDA), IC305.3 (SDI/SDA), J303.2, J304.2, R310.2, U301.DATA
TX: IC301.TXD0 (TX), J301.3; also elsewhere on the board
VIN: C305.1, C306.1, IC303.3 (IN), J302.2, SJ302.3
V_OUT: IC306.1 (DIR), IC306.20 (VCC), SJ302.1, X301.5
WR: IC306.16 (B3), X301.1


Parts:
C401, C405, C407: 0.1u; 0603-CAP
C402, C403: 1u; 0603-CAP
C404, C406: 22u; 0603-CAP
IC401: CP2102; QFN28G_0.5-5X5MM
IC402: LM1117_3V3; SOT223
J401: usb; USB-B-MICRO-SMD_MY
J402: COM1; 2X03_1.27MM_SMT
J403: COM2; 2X03
Q401, Q402: 7002; SOT23-3
R401, R402: 4.7k; R0603
R403, R406: 10k; R0603
R404, R405: 2k; R0603
SW401: RST; MICROPUSH-BUT_TOP
SW402: PRG; MICROPUSH-BUT_TOP

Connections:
+3V3: C401.2, C402.2, C404.1, C405.1, IC401.6 (VDD), IC401.7 (REGIN), IC402.2 (OUT), IC402.4 (OUT), J402.2, J403.2, R401.2, R403.1, R406.2; also elsewhere on the board
DTR: IC401.28 (DTR), Q401.2 (S), R405.1
EN: C403.2, J402.1, J403.1, Q402.3 (D), R403.2, SW401.A; also elsewhere on the board
GND: C401.1, C402.1, C403.1, C404.2, C405.2, C406.2, C407.2, IC401.3 (GND), IC401.29 (GND), IC401.HG1 (GND), IC401.HG2 (GND), IC401.HG3 (GND), IC401.HG4 (GND), IC401.HG5 (GND), IC402.1 (GND), J401.GND, J401.SH@1 (SHIELD), J401.SH@2 (SHIELD), J401.SH@3 (SHIELD), J401.SH@4 (SHIELD), J401.SH@5 (SHIELD), J401.SH@6 (SHIELD), J402.4, J403.4, R402.2, SW401.B, SW401.SH0 (SH), SW402.B, SW402.SH0 (SH); also elsewhere on the board
GPIO0: J402.6, J403.6, Q401.3 (D), R406.1, SW402.A; also elsewhere on the board
unnamed: IC401.4 (D+), J401.D+
unnamed: IC401.5 (D-), J401.D-
unnamed: Q401.1 (G), R404.2
unnamed: Q402.1 (G), R405.2
unnamed: IC401.11 (!SUSPEND), R402.1
unnamed: IC401.9 (!RST), R401.1
RTS: IC401.24 (RTS), Q402.2 (S), R404.1
RX: IC401.26 (TXD), J402.5, J403.5; also elsewhere on the board
TX: IC401.25 (RXD), J402.3, J403.3; also elsewhere on the board
VBUS: C406.1, C407.1, IC401.8 (VBUS), IC402.3 (IN), J401.VBUS



Board: 2 copper layers, 127.0 x 88.9 mm, 124 parts (21 on the bottom side), 203 nets.

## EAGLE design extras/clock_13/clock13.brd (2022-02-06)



Board: 2 copper layers, 57.0 x 70.0 mm, 48 parts (9 on the bottom side), 70 nets.

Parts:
C101, C103, C105, C106, C111, C112, C113: 0.1u; 0603-CAP
C102, C104, C107, C108, C109, C110: 500u; CPOL-RADIAL-100UF-25V
C114, C115, C116: 1u; 0603-CAP
IC101: ESP12-SMD
IC102: ESP32; ESP32-WROOVER/WROOM
IC103: ESP32C3-MODULE13U; ESP32C3-13U
J101, J102, J104: COM; 2X03_SMT
J103, J105, J106: USB-B-MICRO-SMD_MY
J107, J109: 2X8
J108: 2X13
R101, R102, R106, R107, R108: 10k; R0603
R103, R104, R105: 100k; R0603
SJ101, SJ102: L/W; MICROBUILDER_SOLDERJUMPER_ARROW_NOPASTE_3
SJ103: DHT; MICROBUILDER_SOLDERJUMPER_ARROW_NOPASTE
SW101, SW103, SW104: RST; MICROPUSH-BUT_TOP
SW102, SW105, SW106: PRG; MICROPUSH-BUT_TOP
U101, U102, U103: AP2112; SOT23-5

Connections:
1EN_P: R103.2, U103.3
2D+: IC103.IO19, J106.D+
2D-: IC103.IO18, J106.D-
2EN: C116.1, IC103.EN, J102.1, J107.1, R108.1, SW104.B
2EN_P: R104.2, U102.3
2IO0: IC103.IO0, J107.8
2IO1: IC103.IO1, J107.7
2IO2: IC103.IO2, J107.5
2IO3: IC103.IO3, J107.12
2IO4: IC103.IO4, SJ101.1
2IO5: IC103.IO5, J107.9
2IO6: IC103.IO6, J107.10
2IO7: IC103.IO7, J107.16
2IO8: IC103.IO8, J107.14
2IO9: IC103.IO9, J102.6, J107.2, SW106.B
2IO10: IC103.IO10, J107.15
2RX0: IC103.RX0, J102.5
2TX0: IC103.TX0, J102.3
3ADC: IC101.ADC, J109.7, R102.1
3EN: C115.1, IC101.RESET, J101.1, J109.1, R107.1, SW103.B
3EN_P: R105.2, U101.3
3IO0: IC101.GPIO0, J101.6, J109.2, SW105.B
3IO2: IC101.GPIO2, SJ102.1, SJ103.2
3IO4: IC101.GPIO4, J109.9
3IO5: IC101.GPIO5, J109.10
3IO12: IC101.GPIO12, J109.5
3IO13: IC101.GPIO13, J109.16
3IO14: IC101.GPIO14, J109.15
3IO15: IC101.GPIO15, J109.12
3IO16: IC101.GPIO16, J109.14
3RX0: IC101.RXD0, J101.5
3TX0: IC101.TXD0, J101.3
4EN: C114.1, IC102.3, J104.1, J108.1, R106.1, SW101.B
4IO0: IC102.25, J104.6, J108.2, SW102.B
4IO2: IC102.24, IC102.48, J108.12
4IO4: IC102.26, J108.19
4IO5: IC102.29, J108.14
4IO12: IC102.14, J108.20
4IO13: IC102.16, IC102.40, J108.21
4IO14: IC102.13, J108.22
4IO15: IC102.23, IC102.47, J108.23
4IO18: IC102.30, J108.15
4IO19: IC102.31, J108.16
4IO21: IC102.33, J108.24
4IO22: IC102.36, J108.10
4IO23: IC102.37, J108.9
4IO25: IC102.10, J108.17
4IO26: IC102.11, J108.13
4IO27: IC102.12, J108.25
4IO32: IC102.8, J108.26
4IO33: IC102.9, J108.18
4IO34: IC102.6, J108.8
4IO35: IC102.7, J108.11
4RX0: IC102.34, J104.5
4SVN: IC102.5, J108.7
4SVP: IC102.4, J108.5
4TX0: IC102.35, J104.3
+3V3_2: C104.1, C105.2, IC103.3V3, J102.2, J107.4, R108.2, U102.5
+3V3_3: C101.2, C102.1, IC101.VCC, J101.2, J109.4, R101.2, R107.2, U101.5
+3V3_4: C103.2, C108.1, C112.2, IC102.2, J104.2, J108.4, R106.2, U103.5
+5V_2: C110.1, C113.2, J106.VBUS, J107.6, R104.1, U102.1
+5V_3: C109.1, C111.1, J105.VBUS, J109.6, R105.1, U101.1
+5V_4: C106.1, C107.1, J103.VBUS, J108.6, R103.1, U103.1
GND: C101.1, C102.2, C103.1, C104.2, C105.1, C106.2, C107.2, C108.2, C109.2, C110.2, C111.2, C112.1, C113.1, C114.2, C115.2, C116.2, IC101.GND, IC102.1, IC102.15, IC102.38, IC102.39, IC102.GND, IC102.PAD$1, IC102.PAD$4, IC102.PAD$5, IC102.PAD$7, IC102.PAD$8, IC102.PAD$9, IC103.GND, J101.4, J102.4, J103.GND, J103.SH@1, J103.SH@2, J103.SH@3, J103.SH@4, J103.SH@5, J103.SH@6, J104.4, J105.GND, J105.SH@1, J105.SH@2, J105.SH@3, J105.SH@4, J105.SH@5, J105.SH@6, J106.GND, J106.SH@1, J106.SH@2, J106.SH@3, J106.SH@4, J106.SH@5, J106.SH@6, J107.3, J108.3, J109.3, R102.2, SW101.A, SW101.SH0, SW102.A, SW102.SH0, SW103.A, SW103.SH0, SW104.A, SW104.SH0, SW105.A, SW105.SH0, SW106.A, SW106.SH0, U101.2, U102.2, U103.2
IN2_A: J107.13, SJ101.2
IN2_LED: J107.11, SJ101.3
IN3_A: J109.13, SJ102.2
IN3_DHT: J109.8, SJ103.1
IN3_LED: J109.11, SJ102.3
unnamed: IC101.CH_PD, R101.1

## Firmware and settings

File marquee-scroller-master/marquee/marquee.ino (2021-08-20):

/** The MIT License (MIT)

  Copyright (c) 2018 David Payne

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
  THE SOFTWARE IS PROVIDED "AS IS", WITHOUT WARRANTY OF ANY KIND, EXPRESS OR
  IMPLIED, INCLUDING BUT NOT LIMITED TO THE WARRANTIES OF MERCHANTABILITY,
  FITNESS FOR A PARTICULAR PURPOSE AND NONINFRINGEMENT. IN NO EVENT SHALL THE
  AUTHORS OR COPYRIGHT HOLDERS BE LIABLE FOR ANY CLAIM, DAMAGES OR OTHER
  LIABILITY, WHETHER IN AN ACTION OF CONTRACT, TORT OR OTHERWISE, ARISING FROM,
  OUT OF OR IN CONNECTION WITH THE SOFTWARE OR THE USE OR OTHER DEALINGS IN THE
  SOFTWARE.
*/

/**********************************************
  Edit Settings.h for personalization
***********************************************/

#include "Settings.h"

#define VERSION "2.16"

#define HOSTNAME "CLOCK-"
#define CONFIG "/conf.txt"
#define BUZZER_PIN  15

/* Useful Constants */
#define SECS_PER_MIN  (60UL)
#define SECS_PER_HOUR (3600UL)
#ifndef SECS_PER_DAY
#define SECS_PER_DAY  (SECS_PER_HOUR * 24L)
#endif

/* Useful Macros for getting elapsed time */
#define numberOfSeconds(_time_) (_time_ % SECS_PER_MIN)
#define numberOfMinutes(_time_) ((_time_ / SECS_PER_MIN) % SECS_PER_MIN)
#define numberOfHours(_time_) (( _time_% SECS_PER_DAY) / SECS_PER_HOUR)
#define elapsedDays(_time_) ( _time_ / SECS_PER_DAY)

//declairing prototypes
void configModeCallback (WiFiManager *myWiFiManager);
int8_t getWifiQuality();

// LED Settings
const int offset = 1;
int refresh = 0;
String message = "hello";
int spacer = 1;  // dots between letters
int width = 5 + spacer; // The font width is 5 pixels + spacer
Max72xxPanel matrix = Max72xxPanel(pinCS, numberOfHorizontalDisplays, numberOfVerticalDisplays);
String Wide_Clock_Style = "1";  //1="hh:mm Temp", 2="hh:mm:ss", 3="hh:mm"
float UtcOffset;  //time zone offsets that correspond with the CityID above (offset from GMT)

// Time
TimeDB TimeDB("");
String lastMinute = "xx";
int displayRefreshCount = 1;
long lastEpoch = 0;
long firstEpoch = 0;
long displayOffEpoch = 0;
boolean displayOn = true;

// News Client
NewsApiClient newsClient(NEWS_API_KEY, NEWS_SOURCE);
int newsIndex = 0;

// Weather Client
OpenWeatherMapClient weatherClient(APIKEY, CityIDs, 1, IS_METRIC);
// (some) Default Weather Settings
boolean SHOW_DATE = false;
boolean SHOW_CITY = true;
boolean SHOW_CONDITION = true;
boolean SHOW_HUMIDITY = true;
boolean SHOW_WIND = true;
boolean SHOW_WINDDIR = true;
boolean SHOW_PRESSURE = false;
boolean SHOW_HIGHLOW = true;

// OctoPrint Client
OctoPrintClient printerClient(OctoPrintApiKey, OctoPrintServer, OctoPrintPort, OctoAuthUser, OctoAuthPass);
int printerCount = 0;

// Pi-hole Client
PiHoleClient piholeClient;

// Bitcoin Client
BitcoinApiClient bitcoinClient;

ESP8266WebServer server(WEBSERVER_PORT);
ESP8266HTTPUpdateServer serverUpdater;

static const char WEB_ACTIONS1[] PROGMEM = "<a class='w3-bar-item w3-button' href='/'><i class='fas fa-home'></i> Home</a>"
    "<a class='w3-bar-item w3-button' href='/configure'><i class='fas fa-cog'></i> Configure</a>"
    "<a class='w3-bar-item w3-button' href='/configurenews'><i class='far fa-newspaper'></i> News</a>"
    "<a class='w3-bar-item w3-button' href='/configureoctoprint'><i class='fas fa-cube'></i> OctoPrint</a>";

static const char WEB_ACTIONS2[] PROGMEM = "<a class='w3-bar-item w3-button' href='/configurebitcoin'><i class='fab fa-bitcoin'></i> Bitcoin</a>"
    "<a class='w3-bar-item w3-button' href='/configurepihole'><i class='fas fa-network-wired'></i> Pi-hole</a>"
    "<a class='w3-bar-item w3-button' href='/pull'><i class='fas fa-cloud-download-alt'></i> Refresh Data</a>"
    "<a class='w3-bar-item w3-button' href='/display'>";

static const char WEB_ACTION3[] PROGMEM = "</a><a class='w3-bar-item w3-button' href='/systemreset' onclick='return confirm(\"Do you want to reset to default weather settings?\")'><i class='fas fa-undo'></i> Reset Settings</a>"
    "<a class='w3-bar-item w3-button' href='/forgetwifi' onclick='return confirm(\"Do you want to forget to WiFi connection?\")'><i class='fas fa-wifi'></i> Forget WiFi</a>"
    "<a class='w3-bar-item w3-button' href='/restart'><i class='fas fa-sync'></i> Restart</a>"
    "<a class='w3-bar-item w3-button' href='/update'><i class='fas fa-wrench'></i> Firmware Update</a>"
    "<a class='w3-bar-item w3-button' href='https://github.com/Qrome/marquee-scroller' target='_blank'><i class='fas fa-question-circle'></i> About</a>";

static const char CHANGE_FORM1[] PROGMEM = "<form class='w3-container' action='/locations' method='get'><h2>Configure:</h2>"
    "<label>TimeZone DB API Key (get from <a href='https://timezonedb.com/register' target='_BLANK'>here</a>)</label>"
    "<input class='w3-input w3-border w3-margin-bottom' type='text' name='TimeZoneDB' value='%TIMEDBKEY%' maxlength='60'>"
    "<label>OpenWeatherMap API Key (get from <a href='https://openweathermap.org/' target='_BLANK'>here</a>)</label>"
    "<input class='w3-input w3-border w3-margin-bottom' type='text' name='openWeatherMapApiKey' value='%WEATHERKEY%' maxlength='70'>"
    "<p><label>%CITYNAME1% (<a href='http://openweathermap.org/find' target='_BLANK'><i class='fas fa-search'></i> Search for City ID</a>)</label>"
    "<input class='w3-input w3-border w3-margin-bottom' type='text' name='city1' value='%CITY1%' onkeypress='return isNumberKey(event)'></p>"
    "<p><input name='metric' class='w3-check w3-margin-top' type='checkbox' %CHECKED%> Use Metric (Celsius)</p>"
    "<p><input name='showdate' class='w3-check w3-margin-top' type='checkbox' %DATE_CHECKED%> Display Date</p>"
    "<p><input name='showcity' class='w3-check w3-margin-top' type='checkbox' %CITY_CHECKED%> Display City Name</p>"
    "<p><input name='showhighlow' class='w3-check w3-margin-top' type='checkbox' %HIGHLOW_CHECKED%> Display Daily High/Low Temperatures</p>"
    "<p><input name='showcondition' class='w3-check w3-margin-top' type='checkbox' %CONDITION_CHECKED%> Display Weather Condition</p>"
    "<p><input name='showhumidity' class='w3-check w3-margin-top' type='checkbox' %HUMIDITY_CHECKED%> Display Humidity</p>"
    "<p><input name='showwind' class='w3-check w3-margin-top' type='checkbox' %WIND_CHECKED%> Display Wind</p>"
    "<p><input name='showpressure' class='w3-check w3-margin-top' type='checkbox' %PRESSURE_CHECKED%> Display Barometric Pressure</p>"
    "<p><input name='is24hour' class='w3-check w3-margin-top' type='checkbox' %IS_24HOUR_CHECKED%> Use 24 Hour Clock (military time)</p>";

static const char CHANGE_FORM2[] PROGMEM = "<p><input name='isPM' class='w3-check w3-margin-top' type='checkbox' %IS_PM_CHECKED%> Show PM indicator (only 12h format)</p>"
    "<p><input name='flashseconds' class='w3-check w3-margin-top' type='checkbox' %FLASHSECONDS%> Flash : in the time</p>"
    "<p><label>Marquee Message (up to 60 chars)</label><input class='w3-input w3-border w3-margin-bottom' type='text' name='marqueeMsg' value='%MSG%' maxlength='60'></p>"
    "<p><label>Start Time </label><input name='startTime' type='time' value='%STARTTIME%'></p>"
    "<p><label>End Time </label><input name='endTime' type='time' value='%ENDTIME%'></p>"
    "<p>Display Brightness <input class='w3-border w3-margin-bottom' name='ledintensity' type='number' min='0' max='15' value='%INTENSITYOPTIONS%'></p>"
    "<p>Display Scroll Speed <select class='w3-option w3-padding' name='scrollspeed'>%SCROLLOPTIONS%</select></p>"
    "<p>Minutes Between Refresh Data <select class='w3-option w3-padding' name='refresh'>%OPTIONS%</select></p>"
    "<p>Minutes Between Scrolling Data <input class='w3-border w3-margin-bottom' name='refreshDisplay' type='number' min='1' max='10' value='%REFRESH_DISPLAY%'></p>";

static const char CHANGE_FORM3[] PROGMEM = "<hr><p><input name='isBasicAuth' class='w3-check w3-margin-top' type='checkbox' %IS_BASICAUTH_CHECKED%> Use Security Credentials for Configuration Changes</p>"
    "<p><label>Marquee User ID (for this web interface)</label><input class='w3-input w3-border w3-margin-bottom' type='text' name='userid' value='%USERID%' maxlength='20'></p>"
    "<p><label>Marquee Password </label><input class='w3-input w3-border w3-margin-bottom' type='password' name='stationpassword' value='%STATIONPASSWORD%'></p>"
    "<p><button class='w3-button w3-block w3-green w3-section w3-padding' type='submit'>Save</button></p></form>"
    "<script>function isNumberKey(e){var h=e.which?e.which:event.keyCode;return!(h>31&&(h<48||h>57))}</script>";

static const char BITCOIN_FORM[] PROGMEM = "<form class='w3-container' action='/savebitcoin' method='get'><h2>Bitcoin Configuration:</h2>"
    "<p>Select Bitcoin Currency <select class='w3-option w3-padding' name='bitcoincurrency'>%BITCOINOPTIONS%</select></p>"
    "<button class='w3-button w3-block w3-grey w3-section w3-padding' type='submit'>Save</button></form>";

static const char CURRENCY_OPTIONS[] PROGMEM = "<option value='NONE'>NONE</option>"
    "<option value='USD'>United States Dollar</option>"
    "<option value='AUD'>Australian Dollar</option>"
    "<option value='BRL'>Brazilian Real</option>"
    "<option value='BTC'>Bitcoin</option>"
    "<option value='CAD'>Canadian Dollar</option>"
    "<option value='CNY'>Chinese Yuan</option>"
    "<option value='EUR'>Euro</option>"
    "<option value='GBP'>British Pound Sterling</option>"
    "<option value='XAU'>Gold (troy ounce)</option>";

static const char WIDECLOCK_FORM[] PROGMEM = "<form class='w3-container' action='/savewideclock' method='get'><h2>Wide Clock Configuration:</h2>"
    "<p>Wide Clock Display Format <select class='w3-option w3-padding' name='wideclockformat'>%WIDECLOCKOPTIONS%</select></p>"
    "<button class='w3-button w3-block w3-grey w3-section w3-padding' type='submit'>Save</button></form>";

static const char PIHOLE_FORM[] PROGMEM = "<form class='w3-container' action='/savepihole' method='get'><h2>Pi-hole Configuration:</h2>"
    "<p><input name='displaypihole' class='w3-check w3-margin-top' type='checkbox' %PIHOLECHECKED%> Show Pi-hole Statistics</p>"
    "<label>Pi-hole Address (do not include http://)</label><input class='w3-input w3-border w3-margin-bottom' type='text' name='piholeAddress' id='piholeAddress' value='%PIHOLEADDRESS%' maxlength='60'>"
    "<label>Pi-hole Port</label><input class='w3-input w3-border w3-margin-bottom' type='text' name='piholePort' id= 'piholePort' value='%PIHOLEPORT%' maxlength='5'  onkeypress='return isNumberKey(event)'>"
    "<input type='button' value='Test Connection and JSON Response' onclick='testPiHole()'><p id='PiHoleTest'></p>"
    "<button class='w3-button w3-block w3-green w3-section w3-padding' type='submit'>Save</button></form>"
    "<script>function isNumberKey(e){var h=e.which?e.which:event.keyCode;return!(h>31&&(h<48||h>57))}</script>";

static const char PIHOLE_TEST[] PROGMEM = "<script>function testPiHole(){var e=document.getElementById(\"PiHoleTest\"),t=document.getElementById(\"piholeAddress\").value,"
    "n=document.getElementById(\"piholePort\").value;"
    "if(e.innerHTML=\"\",\"\"==t||\"\"==n)return e.innerHTML=\"* Address and Port are required\","
    "void(e.style.background=\"\");var r=\"http://\"+t+\":\"+n;r+=\"/admin/api.php?summary\",window.open(r,\"_blank\").focus()}</script>";

static const char NEWS_FORM1[] PROGMEM =   "<form class='w3-container' action='/savenews' method='get'><h2>News Configuration:</h2>"
    "<p><input name='displaynews' class='w3-check w3-margin-top' type='checkbox' %NEWSCHECKED%> Display News Headlines</p>"
    "<label>News API Key (get from <a href='https://newsapi.org/' target='_BLANK'>here</a>)</label>"
    "<input class='w3-input w3-border w3-margin-bottom' type='text' name='newsApiKey' value='%NEWSKEY%' maxlength='60'>"
    "<p>Select News Source <select class='w3-option w3-padding' name='newssource' id='newssource'></select></p>"
    "<script>var s='%NEWSSOURCE%';var tt;var xmlhttp=new XMLHttpRequest();xmlhttp.open('GET','https://raw.githubusercontent.com/Qrome/marquee-scroller/master/sources.json',!0);"
    "xmlhttp.onreadystatechange=function(){if(xmlhttp.readyState==4){if(xmlhttp.status==200){var obj=JSON.parse(xmlhttp.responseText);"
    "obj.sources.forEach(t)}}};xmlhttp.send();function t(it){if(it!=null){if(s==it.id){se=' selected'}else{se=''}tt+='<option'+se+'>'+it.id+'</option>';"
    "document.getElementById('newssource').innerHTML=tt}}</script>"
    "<button class='w3-button w3-block w3-grey w3-section w3-padding' type='submit'>Save</button></form>";
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
void loop() {
  //Get some Weather Data to serve
  if ((getMinutesFromLastRefresh() >= minutesBetweenDataRefresh) || lastEpoch == 0) {
    getWeatherData();
  }
  checkDisplay(); // this will see if we need to turn it on or off for night mode.

  if (lastMinute != TimeDB.zeroPad(minute())) {
    lastMinute = TimeDB.zeroPad(minute());

    if (weatherClient.getError() != "") {
      scrollMessage(weatherClient.getError());
      return;
    }

    if (displayOn) {
      matrix.shutdown(false);
    }
    matrix.fillScreen(LOW); // show black
    if (OCTOPRINT_ENABLED) {
      if (displayOn && ((printerClient.isOperational() || printerClient.isPrinting()) || printerCount == 0)) {
        // This should only get called if the printer is actually running or if it has been 2 minutes since last check
        printerClient.getPrinterJobResults();
      }
      printerCount += 1;
      if (printerCount > 2) {
        printerCount = 0;
      }
    }

    displayRefreshCount --;
    // Check to see if we need to Scroll some Data
    if (displayRefreshCount <= 0) {
      displayRefreshCount = minutesBetweenScrolling;
      String temperature = weatherClient.getTempRounded(0);
      String description = weatherClient.getDescription(0);
      description.toUpperCase();
      String msg;
      msg += " ";

      if (SHOW_DATE) {
        msg += TimeDB.getDayName() + ", ";
        msg += TimeDB.getMonthName() + " " + day() + "  ";
      }
      if (SHOW_CITY) {
        msg += weatherClient.getCity(0) + "  ";
      }
      msg += temperature + getTempSymbol() + "  ";

      //show high/low temperature
      if (SHOW_HIGHLOW) {
        msg += "High/Low:" + weatherClient.getHigh(0) + "/" + weatherClient.getLow(0) + " " + getTempSymbol() + "  ";
      }

      if (SHOW_CONDITION) {
        msg += description + "  ";
      }
      if (SHOW_HUMIDITY) {
        msg += "Humidity:" + weatherClient.getHumidityRounded(0) + "%  ";
      }
      if (SHOW_WIND) {
        msg += "Wind: " + weatherClient.getDirectionText(0) + " @ " + weatherClient.getWindRounded(0) + " " + getSpeedSymbol() + "  ";
      }
      //line to show barometric pressure
      if (SHOW_PRESSURE) {
        msg += "Pressure:" + weatherClient.getPressure(0) + getPressureSymbol() + "  ";
      }

      msg += marqueeMessage + " ";

      if (NEWS_ENABLED) {
        String news_s =  newsClient.getTitle(newsIndex);
        f_dsp.utf8rus(news_s);
        msg += "  " + NEWS_SOURCE + ": " + news_s + "  ";
        newsIndex += 1;
        if (newsIndex > 9) {
          newsIndex = 0;
        }
      }
      if (OCTOPRINT_ENABLED && printerClient.isPrinting()) {
        msg += "  " + printerClient.getFileName() + " ";
        msg += "(" + printerClient.getProgressCompletion() + "%)  ";
      }
      if (BitcoinCurrencyCode != "NONE" && BitcoinCurrencyCode != "") {
        msg += "  Bitcoin: " + bitcoinClient.getRate() + " " + bitcoinClient.getCode() + " ";
      }
      if (USE_PIHOLE) {
        piholeClient.getPiHoleData(PiHoleServer, PiHolePort);
        piholeClient.getGraphData(PiHoleServer, PiHolePort);
        if (piholeClient.getPiHoleStatus() != "") {
          msg += "    Pi-hole (" + piholeClient.getPiHoleStatus() + "): " + piholeClient.getAdsPercentageToday() + "% ";
        }
      }

      scrollMessage(msg);
      drawPiholeGraph();
    }
  }

  String currentTime = hourMinutes(false);

  if (numberOfHorizontalDisplays >= 8)
  {
    if (Wide_Clock_Style == "1") {
      // On Wide Display -- show the current temperature as well
      String currentTemp = weatherClient.getTempRounded(0);
      String timeSpacer = "  ";
      if (currentTemp.length() >= 3) {
        timeSpacer = " ";
      }
      currentTime += timeSpacer + currentTemp + getTempSymbol();
    }
    if (Wide_Clock_Style == "2") {
      currentTime += secondsIndicator(false) + TimeDB.zeroPad(second());
      matrix.fillScreen(LOW); // show black
    }
    if (Wide_Clock_Style == "3") {
      // No change this is normal clock display
    }
  }
  matrix.fillScreen(LOW);
  centerPrint(currentTime, true);

  if (WEBSERVER_ENABLED) {
    server.handleClient();
  }
  if (ENABLE_OTA) {
    ArduinoOTA.handle();
  }
}

String hourMinutes(boolean isRefresh) {
  if (IS_24HOUR) {
    return TimeDB.zeroPad(hour()) + secondsIndicator(isRefresh) + TimeDB.zeroPad(minute());
  } else {
    return hourFormat12() + secondsIndicator(isRefresh) + TimeDB.zeroPad(minute());
  }
}

String secondsIndicator(boolean isRefresh) {
  String rtnValue = ":";
  if (isRefresh == false && (flashOnSeconds && (second() % 2) == 0)) {
    rtnValue = " ";
  }
  return rtnValue;
}

boolean athentication() {
  if (IS_BASIC_AUTH) {
    return server.authenticate(www_username, www_password);
  }
  return true; // Authentication not required
}

void handlePull() {
  getWeatherData(); // this will force a data pull for new weather
  displayWeatherData();
}

void handleSaveBitcoin() {
  if (!athentication()) {
    return server.requestAuthentication();
  }
  BitcoinCurrencyCode = server.arg("bitcoincurrency");
  writeCityIds();
  bitcoinClient.updateBitcoinData(BitcoinCurrencyCode);  // does nothing if BitCoinCurrencyCode is "NONE" or empty
  redirectHome();
}

void handleSaveWideClock() {
  if (!athentication()) {
    return server.requestAuthentication();
  }
  if (numberOfHorizontalDisplays >= 8) {
    Wide_Clock_Style = server.arg("wideclockformat");
    writeCityIds();
    matrix.fillScreen(LOW); // show black
  }
  redirectHome();
}

void handleSaveNews() {
  if (!athentication()) {
    return server.requestAuthentication();
  }
  NEWS_ENABLED = server.hasArg("displaynews");
  NEWS_API_KEY = server.arg("newsApiKey");
  NEWS_SOURCE = server.arg("newssource");
  matrix.fillScreen(LOW); // show black
  writeCityIds();
  newsClient.updateNews();
  redirectHome();
}

void handleSaveOctoprint() {
  if (!athentication()) {
    return server.requestAuthentication();
  }
  OCTOPRINT_ENABLED = server.hasArg("displayoctoprint");
  OCTOPRINT_PROGRESS = server.hasArg("octoprintprogress");
  OctoPrintApiKey = server.arg("octoPrintApiKey");
  OctoPrintServer = server.arg("octoPrintAddress");
  OctoPrintPort = server.arg("octoPrintPort").toInt();
  OctoAuthUser = server.arg("octoUser");
  OctoAuthPass = server.arg("octoPass");
  matrix.fillScreen(LOW); // show black
  writeCityIds();
  if (OCTOPRINT_ENABLED) {
    printerClient.getPrinterJobResults();
  }
  redirectHome();
}

void handleSavePihole() {
  if (!athentication()) {
    return server.requestAuthentication();
  }
  USE_PIHOLE = server.hasArg("displaypihole");
  PiHoleServer = server.arg("piholeAddress");
  PiHolePort = server.arg("piholePort").toInt();
  writeCityIds();
  if (USE_PIHOLE) {
    piholeClient.getPiHoleData(PiHoleServer, PiHolePort);
    piholeClient.getGraphData(PiHoleServer, PiHolePort);
  }
  redirectHome();
}

void handleLocations() {
  if (!athentication()) {
    return server.requestAuthentication();
  }
  TIMEDBKEY = server.arg("TimeZoneDB");
  APIKEY = server.arg("openWeatherMapApiKey");
  CityIDs[0] = server.arg("city1").toInt();
  flashOnSeconds = server.hasArg("flashseconds");
  IS_24HOUR = server.hasArg("is24hour");
  IS_PM = server.hasArg("isPM");
  SHOW_DATE = server.hasArg("showdate");
  SHOW_CITY = server.hasArg("showcity");
  SHOW_CONDITION = server.hasArg("showcondition");
  SHOW_HUMIDITY = server.hasArg("showhumidity");
  SHOW_WIND = server.hasArg("showwind");
  SHOW_PRESSURE = server.hasArg("showpressure");
  SHOW_HIGHLOW = server.hasArg("showhighlow");
  IS_METRIC = server.hasArg("metric");
  marqueeMessage = decodeHtmlString(server.arg("marqueeMsg"));
  timeDisplayTurnsOn = decodeHtmlString(server.arg("startTime"));
  timeDisplayTurnsOff = decodeHtmlString(server.arg("endTime"));
  displayIntensity = server.arg("ledintensity").toInt();
  minutesBetweenDataRefresh = server.arg("refresh").toInt();
  minutesBetweenScrolling = server.arg("refreshDisplay").toInt();
  displayScrollSpeed = server.arg("scrollspeed").toInt();
  IS_BASIC_AUTH = server.hasArg("isBasicAuth");
  String temp = server.arg("userid");
  temp.toCharArray(www_username, sizeof(temp));
  temp = server.arg("stationpassword");
  temp.toCharArray(www_password, sizeof(temp));
  weatherClient.setMetric(IS_METRIC);
  matrix.fillScreen(LOW); // show black
  writeCityIds();
  getWeatherData(); // this will force a data pull for new weather
  redirectHome();
}

void handleSystemReset() {
  if (!athentication()) {
    return server.requestAuthentication();
  }
  Serial.println("Reset System Configuration");
  if (LittleFS.remove(CONFIG)) {
    redirectHome();
    ESP.restart();
  }
}
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

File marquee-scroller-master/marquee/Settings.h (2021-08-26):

/** The MIT License (MIT)

Copyright (c) 2018 David Payne

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
THE SOFTWARE IS PROVIDED "AS IS", WITHOUT WARRANTY OF ANY KIND, EXPRESS OR
IMPLIED, INCLUDING BUT NOT LIMITED TO THE WARRANTIES OF MERCHANTABILITY,
FITNESS FOR A PARTICULAR PURPOSE AND NONINFRINGEMENT. IN NO EVENT SHALL THE
AUTHORS OR COPYRIGHT HOLDERS BE LIABLE FOR ANY CLAIM, DAMAGES OR OTHER
LIABILITY, WHETHER IN AN ACTION OF CONTRACT, TORT OR OTHERWISE, ARISING FROM,
OUT OF OR IN CONNECTION WITH THE SOFTWARE OR THE USE OR OTHER DEALINGS IN THE
SOFTWARE.
*/

/******************************************************************************
 * This is designed for the Wemos D1 ESP8266
 * Wemos D1 Mini:  https://amzn.to/2qLyKJd
 * MAX7219 Dot Matrix Module 4-in-1 Display For Arduino
 * Matrix Display:  https://amzn.to/2HtnQlD
 ******************************************************************************/
/******************************************************************************
 * NOTE: The settings here are the default settings for the first loading.  
 * After loading you will manage changes to the settings via the Web Interface.  
 * If you want to change settings again in the settings.h, you will need to 
 * erase the file system on the Wemos or use the “Reset Settings” option in 
 * the Web Interface.
 ******************************************************************************/
 
#include <ESP8266WiFi.h>
#include <WiFiClient.h>
#include <ESP8266WebServer.h>
#include <ESP8266HTTPUpdateServer.h>
#include <WiFiManager.h> // --> https://github.com/tzapu/WiFiManager
#include <ESP8266mDNS.h>
#include <ArduinoOTA.h>
#include <FS.h>
#include <LittleFS.h>
#include <SPI.h>
#include <Adafruit_GFX.h> // --> https://github.com/adafruit/Adafruit-GFX-Library
#include <Max72xxPanel.h> // --> https://github.com/markruys/arduino-Max72xxPanel
#include <pgmspace.h>
#include "OpenWeatherMapClient.h"
#include "TimeDB.h"
#include "NewsApiClient.h" 
#include "OctoPrintClient.h"
#include "BitcoinApiClient.h"
#include "PiHoleClient.h"
#include <Fdsp.h>
//******************************
// Start Settings
//******************************

String TIMEDBKEY = ""; // Your API Key from https://timezonedb.com/register
String APIKEY = ""; // Your API Key from http://openweathermap.org/
// Default City Location (use http://openweathermap.org/find to find city ID)
int CityIDs[] = { 5304391 }; //Only USE ONE for weather marquee
String marqueeMessage = "";
boolean IS_METRIC = false; // false = Imperial and true = Metric
boolean IS_24HOUR = false; // 23:00 millitary 24 hour clock
boolean IS_PM = true; // Show PM indicator on Clock when in AM/PM mode
const int WEBSERVER_PORT = 80; // The port you can access this device on over HTTP
const boolean WEBSERVER_ENABLED = true;  // Device will provide a web interface via http://[ip]:[port]/
boolean IS_BASIC_AUTH = false;  // Use Basic Authorization for Configuration security on Web Interface
char www_username[] = "admin";  // User account for the Web Interface
char www_password[] = "password";  // Password for the Web Interface
int minutesBetweenDataRefresh = 15;  // Time in minutes between data refresh (default 15 minutes)
int minutesBetweenScrolling = 1; // Time in minutes between scrolling data (default 1 minutes and max is 10)
int displayScrollSpeed = 25; // In milliseconds -- Configurable by the web UI (slow = 35, normal = 25, fast = 15, very fast = 5)
boolean flashOnSeconds = true; // when true the : character in the time will flash on and off as a seconds indicator

boolean NEWS_ENABLED = true;
String NEWS_API_KEY = ""; // Get your News API Key from https://newsapi.org
String NEWS_SOURCE = "reuters";  // https://newsapi.org/sources to get full list of news sources available

// Display Settings
// CLK -> D5 (SCK)  
// CS  -> D6 
// DIN -> D7 (MOSI)
const int pinCS = 16; // Attach CS to this pin, DIN to MOSI and CLK to SCK (cf http://arduino.cc/en/Reference/SPI )
int displayIntensity = 5;  //(This can be set from 0 - 15)
const int numberOfHorizontalDisplays = 4; // default 4 for standard 4 x 1 display Max size of 16
const int numberOfVerticalDisplays = 1; // default 1 for a single row height
/* set ledRotation for LED Display panels (3 is default)
0: no rotation
1: 90 degrees clockwise
2: 180 degrees
3: 90 degrees counter clockwise (default)
*/
int ledRotation = 3;

String timeDisplayTurnsOn = "06:30";  // 24 Hour Format HH:MM -- Leave blank for always on. (ie 05:30)
String timeDisplayTurnsOff = "23:00"; // 24 Hour Format HH:MM -- Leave blank for always on. Both must be set to work.
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

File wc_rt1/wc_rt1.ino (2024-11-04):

//------------------------------------------------------
//#include ".\headers\conf.h"
#include "conf.h"


char tstr[25];

// ---------------------------------------------------- Common
const char *conf_f = "/config.json";  // config file name

String from_client = String();

int boot_mode = 1;

uint32_t serv_ms = 60000;

static bool wasAlarm = false;
static bool play_snd = false;

static uint16_t cur_br = 0;

//---------------------------------------------------------------------------------------------------
static byte screen[64];        // display buffer
static uint8_t text_size = 1;  // размер текста
static uint8_t newsIndex;
String local_ip = "192.168.0.0", ns = String();

//---------------------------------------------------------------------------------------------------
snr_data_t snr_data;
snr_cfg_t snr_cfg_data;
conf_data_t conf_data;
hw_data_t hw_data;
wf_data_t wf_data_cur;
wf_data_t wf_data;
#if defined(__xtensa__) || CONFIG_IDF_TARGET_ESP32C3
wifi_cfg_data_t wifi_data;
wifi_cur_data_t wifi_data_cur;
#endif
rtc_hw_data_t rtc_hw;
rtc_cfg_data_t rtc_cfg;
rtc_time_data_t rtc_time;
rtc_alm_data_t rtc_alm;

// ---------------------------------------------------- Constructors
#if defined(__xtensa__) || CONFIG_IDF_TARGET_ESP32C3
ES e_srv;
NF nsys;
WF wifi;
WFJS wifi_cfg;
LFS lfs;

udp_cons print_console_udp;
#endif

MAINJS maincfg;

// ----------------------------------- Web server
#if defined(ESP8266)
ESP8266WebServer server(80);
#elif CONFIG_IDF_TARGET_ESP32 || CONFIG_IDF_TARGET_ESP32S2 || CONFIG_IDF_TARGET_ESP32C3
WebServer server(80);
#endif

// ---------------------------------------------------- HW info
#if defined(ESP8266)
ESP8266HWInfo hwi;
#endif

// ---------------------------------------------------- LM
BH1750 lightMeter;

// ---------------------------------------------------- Other
FD f_dsp2;  //For Display
MyDsp mydsp;

Synt Buzz;  //Конструктор пищалки

CT myrtc;        //For RTC Common
RTCJS myrtccfg;  //For RTC Config
SF hw_chk;       //For HW Check
SNR sens_f;      //For Sensor Common
SNRJS mysnrcfg;  //For Sensor Config

#if defined(__xtensa__) || CONFIG_IDF_TARGET_ESP32C3
// ---------------------------------------------------- News Client
NewsApiClient *newsClient;
#endif

/////////////////////////////////////////////////////////////////////////////////////////////////////////////////////////////////////////////////////////////////////////////////////////////////////////////////////////////////////////
void setup() {
  //------------------------------------------------------  Определяем консоль
  DBG_OUT_PORT.begin(115200);


#if defined(ESP8266)
  //------------------------------------------------------  Get system information
  hwi.info();
#endif
#if defined(__xtensa__) || CONFIG_IDF_TARGET_ESP32C3
  //------------------------------------------------------  Запускаем LittleFileSystem
  lfs.begin();
  DBG_OUT_PORT.println(F("LittleFS started"));

  //------------------------------------------------------  Загружаем конфигурацию

  //------------------------------------------------------  Читаем установки WiFi из конфиг файла
  conf_f = "/conf_wifi.json";
  from_client = lfs.readFile(conf_f);
  if (from_client == "Failed to open file for reading") {
    DBG_OUT_PORT.println(F("Failed to open conf_wifi.json for reading. Using default configuration!!!"));
    wifi_data = wifi_cfg.def_conf();
    from_client = wifi_cfg.to_json(wifi_data);
    lfs.writeFile(conf_f, from_client.c_str());
  } else {
    wifi_data = wifi_cfg.from_json(from_client);
  }
  DBG_OUT_PORT.print(conf_f);
  DBG_OUT_PORT.println(F(" loaded"));

  //--------------------------------------------------------  Запускаем основные сетевые сервисы
  //--------------------------------------------------------  Запускаем WiFi
  wifi_data_cur = wifi.begin(wifi_data);

  if (wifi_data_cur.cli || wifi_data_cur.ap) {
    //------------------------------------------------------  Переопределяем консоль
    if (conf_data.udp_mon) {
      //DBG_OUT_PORT.end();
      //DBG_OUT_PORT = *udp_cons;
      //IP_Addr.fromString(conf_data.srudp_addr);
      //DBG_OUT_PORT.begin(4023, IP_Addr);
      //DBG_OUT_PORT.setDebugOutput(true);
    }

    //------------------------------------------------------  Запускаем сервер, ОТА, MDNS
    nsys.OTA_init(wifi_data.ap_ssid, wifi_data.ap_pass);

    MDNS.begin(wifi_data.ap_ssid);
    DBG_OUT_PORT.print(F("Open http://"));
    DBG_OUT_PORT.print(wifi_data.ap_ssid);
    DBG_OUT_PORT.print(F(".local/edit to see the file browser\n"));

    web_setup();
    start_serv();
  }
  strcpy(tstr, "Safe Mode");
#endif

  //------------------------------------------------------  Читаем установки RTC из конфиг файла
  conf_f = "/conf_rtc.json";
#if defined(__xtensa__) || CONFIG_IDF_TARGET_ESP32C3
  from_client = lfs.readFile(conf_f);
  if (from_client == "Failed to open file for reading") {
    DBG_OUT_PORT.println(F("Failed to open conf_rtc.json for reading. Using default configuration!!!"));
    rtc_cfg = myrtccfg.def_conf();
    from_client = myrtccfg.to_json(rtc_cfg);
    lfs.writeFile(conf_f, from_client.c_str());
  } else {
    rtc_cfg = myrtccfg.from_json(from_client);
  }
#else
  rtc_cfg = myrtccfg.from_json(from_client);
#endif
  DBG_OUT_PORT.print(conf_f);
  DBG_OUT_PORT.println(F(" loaded"));

  //------------------------------------------------------  Загружаем настройки датчиков
  conf_f = "/conf_snr.json";
#if defined(__xtensa__) || CONFIG_IDF_TARGET_ESP32C3
  from_client = lfs.readFile(conf_f);
  if (from_client == "Failed to open file for reading") {
    DBG_OUT_PORT.println(F("Failed to open conf_snr.json for reading. Using default configuration!!!"));
    snr_cfg_data = mysnrcfg.def_conf();
    from_client = mysnrcfg.to_json(snr_cfg_data);
    lfs.writeFile(conf_f, from_client.c_str());
  } else {
    snr_cfg_data = mysnrcfg.from_json(from_client);
  }
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

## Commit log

2018-08-13 Add matrix 32x64 for esp32
2018-08-14 Adopt for esp32 (compartible with tone())
2018-08-14 Moved to esp32 step2
2018-08-19 Esp32 forwarded
2021-02-18 replace max7219 render mechanism
    [boot.ino, m7219.ino, mode_scr.ino]
2021-02-25 broken scrolling return ht33 14s x8
    [boot.ino, conf.h, mode_scr.ino]
2021-03-17 new board
2021-03-17 add snd&led out inversion
2021-03-25 fix prototypes
2021-06-15 esp32 adopt
2021-06-29 esp32 upd
2021-06-29 esp32 upd2
2021-07-11 adopt for esp32 (beta)
2021-07-16 snd for esp32 return
2021-07-16 esp32 optimized
2021-07-18 irq for esp32
2021-07-24 http update for esp32 return
2021-07-27 replace type of st1 from string to char*
    [boot.ino, disp.ino, msg_for_scroll.ino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]
2021-08-27 adopt for new red board
2021-09-09 conf adopt for esp32
2021-10-19 add board max7219
    [8x8x8m7219.brd, 8x8x8m7219.sch, bom.xlsx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]
2021-10-19 add esp32 board
    [7219_32_16.brd, 7219_32_16.sch, bom.xlsx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]
2021-10-28 с3 upd
2021-11-12 add new board
    [clock10.brd, clock10.sch]
2021-11-17 fix spi init
2021-11-23 upd lib
    [clock10.brd, clock10.sch]
2021-11-23 add s2
    [clock10.brd, clock10.sch]
2022-01-10 add one wire
2022-01-14 add new boards
    [clock10.brd, clock10.sch, clock12.brd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]
2022-01-15 upg board
    [esp32_hub75.brd, esp32_hub75.sch]
2022-01-21 add relay
    [clock12.sch]
2022-01-31 add test wifi + new boards
    [clock13.brd, clock13.sch]
2022-02-06 bug fix
    [clock10.brd, clock10.sch, clock13.brd]
2022-02-10 add m7219 test
    [clock10.sch, clock14.brd, clock14.sch]
2022-02-18 migrate to json rec / first fix result
    [conf.h, script.js]
2022-02-19 migrate to json fix step3
    [boot.ino, conf.h, func.ino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]
2022-02-21 set time not working prop
    [script.js]
2022-03-03 mod stru 5 unstable
    [boot.ino, cfg.cpp, conf.h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]
2023-01-29 add touch button test
2023-01-31 mod for relay, mod def conf mech
2023-01-31 little fix for avr
    [cfg.cpp, func.cpp, wc_rt1.ino]
2023-02-03 mod for new makuna stage 2(stable)
2023-02-10 relay mod step 1
2023-02-12 Add files via upload
    mod relay
2023-02-13 relay mod (stage 3)
2023-02-13 relay mod (stable)

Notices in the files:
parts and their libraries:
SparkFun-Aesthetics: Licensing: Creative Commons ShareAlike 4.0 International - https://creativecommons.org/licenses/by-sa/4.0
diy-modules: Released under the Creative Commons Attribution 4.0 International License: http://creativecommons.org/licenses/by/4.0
